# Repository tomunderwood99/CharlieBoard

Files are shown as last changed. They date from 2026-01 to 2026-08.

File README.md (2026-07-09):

# The CharlieBoard







An open-source LED display system for the MBTA that runs on Raspberry Pi Zero 2W with WS2812B LEDs. Features real-time transit data visualization, web control interface, and geographically accurate station mapping. PCBs for the Red, Orange, and Blue line are live! Green line in progress :)

CharlieBoard Display

## Quick Start

**Prerequisites:** 
- Raspberry Pi Zero 2W with Debian Trixie 64-bit Lite
- WS2812B LED strip or custom PCB
- WiFi (configured during pi setup)
- SSH enabled (RPI Connect recommended)
- [MBTA API key](https://api-v3.mbta.com/)

For hardware assembly instructions, see the [Hardware Assembly Guide](docs/hardware_assembly_guide.md).

Run the following commands to install and initialize the display.

```bash
sudo apt update && sudo apt install -y git python3-pip

cd ~
git clone --filter=blob:none --sparse https://github.com/tomunderwood99/CharlieBoard.git

cd CharlieBoard
git sparse-checkout set --no-cone '/*' '!hardware'

chmod +x deployment/quick_start/setup_mbta_controller.sh

# Optional: use flags to set custom recovery wifi settings:
# --with-wifi-helper
# --ap-ssid "CustomWifiName"
# --ap-password "YourStrongPassword"

sudo ./deployment/quick_start/setup_mbta_controller.sh
```

The setup script will prompt for your MBTA API key and various setting inputs. After completion, access the web interface at `http://your-hostname.local:8000` on your local network. Settings can be changed from the web interface or from the command line using the `charlieboard` command. See the [CLI reference](docs/cli.md) for details.

**Optional enhancement:** Set up a reverse proxy to access the web interface at `http://hostname.local` without the port number. See the [nginx reverse proxy setup guide](docs/nginx_reverse_proxy_setup.md).

**Note:** The sparse-checkout excludes the `hardware/` directory (PCB design files) to speed up cloning. This setting persists across future `git pull` operations. If you need the hardware files, run: `git sparse-checkout disable`

## Features

- **Real-time Transit Data**: Live vehicle positions, occupancy, and speed data
- **Geographically Accurate**: Stations are marked on a real map
- **Web Control Interface**: Remote control from any device on your network
- **Customizable Display**: Adjustable brightness, colors, and display hours
- **Reliable Operation**: Automatic recovery, health monitoring, and maintenance

## Hardware

| Component | Notes |
|---|---|
| Raspberry Pi Zero 2W | Main controller |
| WS2812B LEDs | Custom PCB (\~\$120 for 5) or LED strips (\~\$20) |
| 5V 4A Power Supply | Powers Pi and LEDs |
| MicroSD Card (16GB+) | For OS and software |
| Display Enclosure | Picture frame or custom case |

**Total Cost**: $50–180 depending on LED choice

Complete PCB design files (Gerber + KiCad) are available in `hardware/PCB Production/`. See the [Bill of Materials](docs/bill_of_materials.md) for detailed pricing and sourcing.

## Documentation

| Guide | Description |
|---|---|
| [Quick Start Guide](deployment/quick_start/QUICK_START_GUIDE.md) | Step-by-step setup walkthrough |
| [Terminal CLI](docs/cli.md) | Change settings from SSH without the web UI |
| [Complete Setup Guide](docs/complete_setup_guide.md) | Detailed manual configuration |
| [Bill of Materials](docs/bill_of_materials.md) | Hardware pricing and sourcing |
| [Hardware Assembly](docs/hardware_assembly_guide.md) | PCB assembly instructions |
| [Operations & Troubleshooting](docs/operations_and_troubleshooting.md) | Maintenance and problem solving |
| [Transit System Adaptation](docs/transit_system_adaptation_guide.md) | Adapt for other transit systems |
| [Map Making with QGIS](docs/map_making_with_qgis.md) | Create custom transit maps ([example project](https://drive.google.com/drive/folders/1vFNIh-ThJNZXUUT2JSJMrOyUVWq9bhA2?usp=drive_link)) |

## Contributing

Contributions are welcome! Please:

1. Fork the repository
2. Create a feature branch (`git checkout -b feature/amazing-feature`)
3. Test on Raspberry Pi Zero 2W hardware
4. Commit your changes (`git commit -m 'Add amazing feature'`)
5. Push and open a Pull Request

Follow existing code style, update documentation for new features, and add comments for complex logic. Contributions to **software** are under the MIT License; contributions to **`hardware/`** design files are under CERN-OHL-S, as described in [License](#license).

## License

This repository uses two licenses:

| Scope | License | Full text |
|---|---|---|
| **Software** (Python, scripts, configs, docs outside `hardware/`, and everything except the `hardware/` tree) | [MIT License](https://opensource.org/licenses/MIT) | [LICENSE](LICENSE) |
| **`hardware/`** (PCB designs, KiCad projects, Gerbers, and related production files in this directory) | [CERN Open Hardware Licence v2 — Strongly Reciprocal (CERN-OHL-S)](https://ohwr.org/project/cernohl/wikis/Documents/CERN-OHL-version-2) | [LICENSE-CERN-OHL-S](LICENSE-CERN-OHL-S) |

Third-party materials bundled under `hardware/` may carry their own licenses (see notices in those subfolders).

Copyright © 2025 Thomas Underwood

<details>
<summary>Disclaimers & Attributions</summary>

### AI Assistance
This project was developed with the assistance of AI coding tools. All code has been reviewed, tested, and validated on actual hardware.

### Data Sources
This project uses data from:
- **MBTA and MassDOT** – Transit data via [MBTA V3 API](https://api-v3.mbta.com/)
- **MassGIS** – Geographic and mapping data

All data is provided "as is" without warranties. This project is not affiliated with, endorsed by, or sponsored by MBTA, MassDOT, MassGIS, or the Commonwealth of Massachusetts.
</details>

## Support

- Check the [Operations and Troubleshooting Guide](docs/operations_and_troubleshooting.md)
- Review logs: `sudo journalctl -u mbta_display -n 100`
- Open an issue on GitHub with your Pi model, OS version, and error details
- [MBTA V3 API Documentation](https://api-v3.mbta.com/) · [Raspberry Pi GPIO Pinout](https://pinout.xyz/) · [Adafruit NeoPixel Guide](https://learn.adafruit.com/adafruit-neopixel-uberguide)

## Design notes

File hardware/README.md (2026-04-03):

# Hardware

Design files in this directory (KiCad projects, Gerbers, BOM-related assets, and other PCB production materials) are licensed under **CERN Open Hardware Licence Version 2 — Strongly Reciprocal (CERN-OHL-S)**.

The complete license text is in the repository root: [LICENSE-CERN-OHL-S](../LICENSE-CERN-OHL-S). The rest of the CharlieBoard repository (software, deployment scripts, and documentation outside `hardware/`) is under the MIT License: [LICENSE](../LICENSE).

Some subfolders include third-party symbols or footprints with their own license files—check those folders for additional terms.

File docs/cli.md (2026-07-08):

# CharlieBoard terminal CLI

Manage display settings from SSH or Raspberry Pi Connect without using the web UI on port 8000.

Install with the project (`pip install -e .`). The setup script puts `venv/bin` on your PATH in `/etc/profile.d/mbta_led_controller.sh`, so `charlieboard` works in new SSH or Pi Connect sessions. In the same terminal window where you just ran setup, use the full path once: `~/CharlieBoard/venv/bin/charlieboard show`.

## Commands

### Show settings

```bash
charlieboard show
```

Prints route, display mode, power, bedtimes, brightness, and colors.

### Set display mode

```bash
charlieboard set mode vehicles    # vehicles | occupancy | speed | rainbow
```

Picked up by the running display on the next MBTA stream event (usually within seconds).

### Set power

```bash
charlieboard set power on
charlieboard set power off
```

### Set brightness

```bash
charlieboard set brightness 0.5
charlieboard set brightness 1.0
```

Brightness is on a 0.0–1.0 scale (same as the web UI slider). Picked up by the running display on the next stream event.

### Set bedtimes

```bash
charlieboard set bedtime --start 22:00 --end 07:00
charlieboard set bedtime --start 23:30    # end unchanged
charlieboard set bedtime --end 06:00      # start unchanged
```

Times use 24-hour `HH:MM` format.

### Set colors (legend / color keys)

```bash
charlieboard set color stopped 255,0,0
charlieboard set color incoming #ff4b4b
charlieboard set color max_occupancy 255 128 0
```

**Color names**

| Mode | Names |
|---|---|
| vehicles | `stopped`, `incoming`, `transit` |
| speed | `min_speed`, `max_speed`, `null_speed` |
| occupancy | `min_occupancy`, `max_occupancy`, `null_occupancy` |

**Color formats:** `#RRGGBB`, `R,G,B`, or `R G B` (0–255 per channel).

### Set route

```bash
sudo charlieboard set route Green-B
```

Valid routes: `Red`, `Blue`, `Orange`, `Green-All`, `Green-B`, `Green-C`, `Green-D`, `Green-E`.

Route changes require restarting services (station maps and the MBTA stream filter are set at startup). The CLI restarts `mbta_display` and `mbta_monitor` automatically after saving. Use `sudo` if `systemctl restart` needs elevated permissions.

### Custom .env path

```bash
charlieboard --env /path/to/.env show
```

## Web UI sync

- Settings are stored in `.env`; the web UI reads the same file on page load (`GET /get_settings`).
- Reload the browser after CLI changes to refresh the form.
- The web UI does not display route (setup-only); saving from the web will not overwrite a CLI route change.

## Related commands

| Command | Purpose |
|---|---|
| `display_status` | System health and metrics |
| `display_reboot` | Restart display + monitor services |

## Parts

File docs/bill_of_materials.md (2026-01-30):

# Bill of Materials

Complete parts list for building The CharlieBoard.

## Cost Summary

| Category | Cost |
|---|---|
| Electronics | ~$165 |
| Hardware & Enclosure | ~$12 |
| **Total** | **~$177** |

*Most of the cost is the custom PCB (5-board minimum). Using LED strips instead brings total to ~$50.*

## Electronics

| Component | Qty | Price | Notes |
|---|-----|---|---|
| Raspberry Pi Zero 2W | 1 | $15 | Main controller |
| MicroSD Card (16GB+) | 1 | $8 | For OS and software |
| Custom PCB | 5 | $120 | With 47 WS2812B LEDs (assembled, min order 5) |
| 5V 4A USB-C Power Supply | 1 | $12 | Powers Pi and LEDs |
| USB-C to Wire Connector | 1 | $3 | Power connection |
| 1N5819 Schottky Diode | 1 | $0.25 | Protects GPIO pin |
| 3-pin JST Connectors | 2 | $1.50 | PCB power connection |
| Misc Wires | 1 set | $3 | Hookup wire |
| Heat Shrink Tubing | 1 set | $2 | Wire insulation |

## Hardware & Enclosure

| Component | Qty | Price | Notes |
|---|-----|---|---|
| 8"×10" Picture Frame | 1 | $10 | Display enclosure (remove glass) |
| 3D Printed Pi Case | 1 | $0.50 | ~15g PLA |
| M2.5×12mm Screws | 4 | $0.60 | Pi mounting |
| M2.5 Nuts | 4 | $0.40 | Pi mounting |

## Component Notes

### Raspberry Pi Zero 2W
Tested on Zero 2W, should work on Pi 3/4/5. Purchase from [Adafruit](https://www.adafruit.com/), [PiShop](https://www.pishop.us/), or [CanaKit](https://www.canakit.com/).

### Custom PCB
- Design files in `hardware/PCB Production/`
- Recommended: [JLCPCB](https://jlcpcb.com/) with assembly service
- WS2812B-2020 LEDs require baking before assembly—see [datasheet](https://www.mouser.com/pdfDocs/WS2812B-2020_V10_EN_181106150240761.pdf)

### 1N5819 Schottky Diode
Protects GPIO from backflow current. Critical for safe operation.

### Picture Frame
8"×10" works for Red Line PCB. Remove glass; modify back panel for JST connector clearance.

### 3D Printed Case
STL files in `hardware/RPI Case/`. Print at home or order from Craftcloud, Shapeways, etc.

## Budget Build (~$50)

Skip the custom PCB for a minimal working system:

| Component | Price |
|---|---|
| Raspberry Pi Zero 2W | $15 |
| MicroSD Card | $8 |
| WS2812B LED Strip | $12 |
| 5V Power Supply | $10 |
| Misc Electronics | $5 |

**Trade-off:** Not geographically accurate, requires custom mounting.

## Self-Assembly PCB Option

Order bare PCBs (~$2–5 each) and hand-solder components.
- **Savings:** ~$60–80 per board
- **Difficulty:** High—WS2812B-2020 LEDs are 2mm × 2mm, requires reflow oven

## Bulk Orders

Custom PCB cost drops significantly with quantity. At 5 boards, cost is ~$24/board, bringing total build cost to ~$80 if the boards are split between 5 people.

## Where to Buy

| Category | Suppliers |
|---|---|
| Electronics | Adafruit, DigiKey, Mouser, Amazon |
| PCB Manufacturing | JLCPCB (recommended), PCBWay, OSH Park |
| 3D Printing | Local maker spaces, Craftcloud, Shapeways |

## Not Included

- Soldering equipment (iron, solder, flux)
- Tools (wire strippers, screwdrivers, multimeter)
- Prices are estimates and vary by region/supplier

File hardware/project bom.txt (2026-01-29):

1x PCB or WS2812 string with appropriate leds (47 for Red Line)
1x Raspberry Pi Zero 2W
1x MicroSD Chip
1x 8"x10" Picture Frame
1x 3D printed RPI case
4x M2.5x12mm screws
4x M2.5 nuts 

1x 5v4A USBC Power Supply (can sub for other connection type)
1x 1N5819 Schottky Diode
1x USBC-to-wire connector
1x 3 pin JST female surface mount connector
1x 3 pin JST male wired connector
Misc wires
Soldering station
Heat shrink tubing

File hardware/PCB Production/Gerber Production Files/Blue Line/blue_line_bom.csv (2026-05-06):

Comment | Designator | Footprint | JLCPCB Part #_optional_
WS2812B-202 | D1,D2,D3,D4,D5,D6,D7,D8,D9,D10,D11,D12,D13,D14,D15,D16,D17,D18,D19,D20,D21,D22,D23,D24 | LED_WS2812B-2020 | C965555

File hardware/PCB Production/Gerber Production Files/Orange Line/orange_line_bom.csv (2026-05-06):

Comment | Designator | Footprint | JLCPCB Part #_optional_
WS2812B-202 | D1,D2,D3,D4,D5,D6,D7,D8,D9,D10,D11,D12,D13,D14,D15,D16,D17,D18,D19,D20,D21,D22,D23,D24,D25,D26,D27,D28,D29,D30,D31,D32,D33,D34,D35,D36,D37,D38,D39,D40 | LED_WS2812B-2020 | C965555

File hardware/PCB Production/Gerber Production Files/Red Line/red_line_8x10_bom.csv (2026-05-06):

Comment | Designator | Footprint | JLCPCB Part #_optional_
WS2812B-2020 | U2, U3, U4, U5, U6, U7, U8, U9, U10, U11, U12, U13, U14, U15, U16, U17, U18, U19, U20, U21, U22, U23, U24, U25, U26, U27, U28, U29, U30, U31, U32, U33, U34, U35, U36, U37, U38, U39, U40, U41, U42, U43, U44, U45, U46, U47, U48 | LED_WS2812B-2020 | C965555

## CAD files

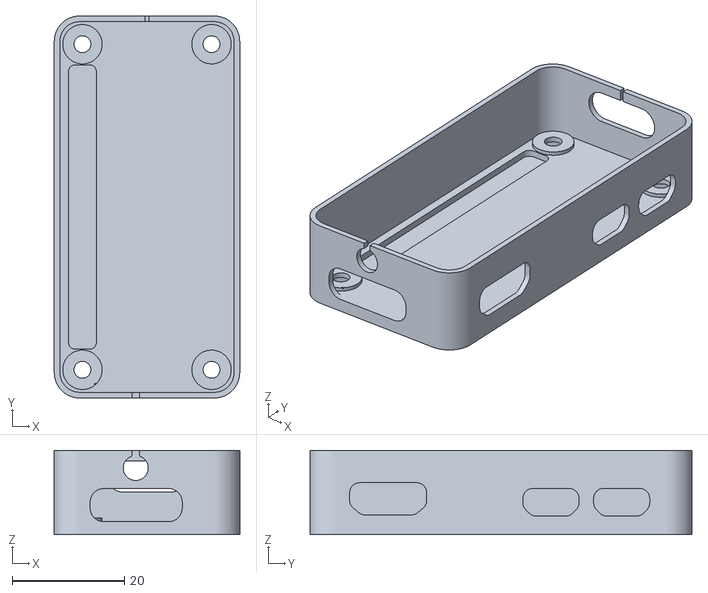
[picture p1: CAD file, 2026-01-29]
hardware/RPI Case/rpi_z2w_case_body.stl
33.0 x 68.0 x 15.0

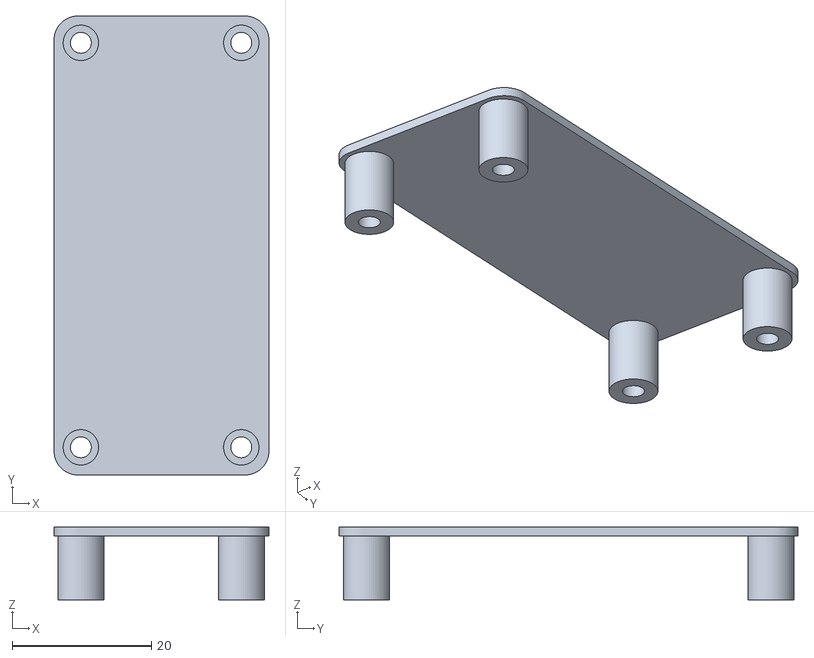
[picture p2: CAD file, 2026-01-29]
hardware/RPI Case/rpi_z2w_case_lid.stl
30.8 x 65.8 x 10.4

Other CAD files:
hardware/RPI Case/rpi_z2w_case.f3z

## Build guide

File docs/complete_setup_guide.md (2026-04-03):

# Complete Setup Guide

This guide walks through setting up **CharlieBoard** on a fresh Raspberry Pi Zero 2W manually. For most users, the [Quick Start Guide](../deployment/quick_start/QUICK_START_GUIDE.md) or the automated installer (below) is faster.

**Automated setup (recommended):** From the repository root on the Pi, run:

```bash
cd ~/CharlieBoard   # or your clone directory
chmod +x deployment/quick_start/setup_mbta_controller.sh
sudo ./deployment/quick_start/setup_mbta_controller.sh
```

That script performs the same stages as this document: system packages, timezone, virtualenv, `pip install -e .`, `.env` creation, systemd unit path patching, log directory, service install, optional LED test, and `display_status` / `display_reboot` aliases in `~/.bashrc`. Use this guide if you need to install or debug step by step.

**Note:** This covers software setup only. For hardware assembly, see the [Hardware Assembly Guide](hardware_assembly_guide.md) first.

## Table of Contents

1. [Prepare Your Raspberry Pi](#step-1-prepare-your-raspberry-pi)
2. [System Update and Core Tools](#step-2-system-update-and-core-tools)
3. [Clone the Repository](#step-3-clone-the-repository)
4. [Configure Timezone](#step-4-configure-timezone)
5. [Set Up Python Environment](#step-5-set-up-python-environment)
6. [Install Dependencies](#step-6-install-dependencies)
7. [Set Up Raspberry Pi Connect (Optional)](#step-7-set-up-raspberry-pi-connect-optional)
8. [Create Configuration File](#step-8-create-configuration-file)
9. [Configure LED Mappings (Optional)](#step-9-configure-led-mappings-optional)
10. [Test LED Hardware](#step-10-test-led-hardware)
11. [Test Full Application](#step-11-test-full-application)
12. [Patch Paths in Systemd Unit Files](#step-12-patch-paths-in-systemd-unit-files)
13. [Install and Enable Services](#step-13-install-and-enable-services)
14. [Verify Services](#step-14-verify-services)
15. [Set Up Convenience Aliases (Optional)](#step-15-set-up-convenience-aliases-optional)
16. [Access Web Interface](#step-16-access-web-interface)

## Step 1: Prepare Your Raspberry Pi

1. **Flash Raspberry Pi OS** using [Raspberry Pi Imager](https://www.raspberrypi.com/software/):
   - Choose **Raspberry Pi OS Lite (64-bit)**
   - Configure WiFi and SSH in imager settings
   - Set hostname (e.g., `mbta-display`)
   - Set username and password

2. **Connect via SSH:**
   ```bash
   ssh pi@mbta-display.local
   # or: ssh pi@192.168.1.xxx
   ```

## Step 2: System Update and Core Tools

The automated installer runs `apt-get update` and installs the packages below (it does not run a full `dist-upgrade`). Match that set for manual setup:

```bash
sudo apt update
sudo apt install -y python3 python3-pip python3-venv python3-dev git
# Optional but recommended for a new image:
# sudo apt upgrade -y
```

Verify:

```bash
git --version && python3 --version
```

Python 3.7+ is required (`timedatectl` and `systemctl` are expected on Raspberry Pi OS).

## Step 3: Clone the Repository

```bash
cd ~
git clone https://github.com/tomunderwood99/CharlieBoard.git
cd CharlieBoard

# Optional: Remove hardware folder to save space
rm -rf hardware/
echo "hardware/" >> .git/info/exclude
```

The installer expects to be run from the directory that contains `runtime/startup.py` and `setup.py` (repository root).

## Step 4: Configure Timezone

The setup script configures timezone **before** creating the virtualenv. Set yours explicitly:

```bash
sudo timedatectl set-timezone America/New_York
timedatectl
```

Other US examples: `America/Chicago`, `America/Denver`, `America/Los_Angeles`.

## Step 5: Set Up Python Environment

```bash
cd ~/CharlieBoard
python3 -m venv venv
source venv/bin/activate
pip install --upgrade pip

# Verify: should show .../CharlieBoard/venv/bin/python (path depends on user and clone location)
which python
```

The installer creates the venv as your normal user (`SUDO_USER`), not as root.

## Step 6: Install Dependencies

```bash
pip install -e .
```

Verify key packages:

```bash
pip list | grep -E "Flask|neopixel|rpi-ws281x"
```

If installation fails, the installer suggests:

```bash
sudo apt install -y build-essential python3-dev
# For some rpi_ws281x build issues:
sudo apt install -y scons swig
```

Then retry `pip install -e .` (or `pip install -e . -v` for verbose output).

## Step 7: Set Up Raspberry Pi Connect (Optional but Recommended)

[Raspberry Pi Connect](https://www.raspberrypi.com/documentation/services/connect.html) provides secure remote access via web browser—no port forwarding or VPN needed. Manage your display from anywhere.

```bash
sudo apt install rpi-connect
rpi-connect signin
```

Visit the displayed URL to complete sign-in with your [Raspberry Pi ID](https://id.raspberrypi.com). After setup, access your Pi at [connect.raspberrypi.com](https://connect.raspberrypi.com).

## Step 8: Create Configuration File

Create `.env` in the project root (`~/CharlieBoard/.env`). The installer writes this template (adjust values as needed):

```bash
nano .env
```

Contents (same fields as the setup script):

```bash
# CharlieBoard / MBTA configuration

MBTA_API_KEY=your_api_key_here

# Display settings
ROUTE=Red
BRIGHTNESS=0.5
POWER_SWITCH=on
BEDTIME_START=22:00
BEDTIME_END=06:00
DISPLAY_MODE=vehicles

# Color settings (RGB values)
STOPPED_COLOR=[255, 0, 0]
INCOMING_COLOR=[255, 75, 75]
TRANSIT_COLOR=[150, 150, 150]
MIN_SPEED_COLOR=[0, 255, 0]
MAX_SPEED_COLOR=[255, 0, 0]
NULL_SPEED_COLOR=[0, 0, 255]
MIN_OCCUPANCY_COLOR=[0, 255, 0]
MAX_OCCUPANCY_COLOR=[255, 0, 0]
NULL_OCCUPANCY_COLOR=[0, 0, 255]

# Debug settings
SHOW_DEBUGGER_OPTIONS=false
DEBUGGER=[]
```

Get a free API key at [api-v3.mbta.com](https://api-v3.mbta.com/). For `ROUTE`, the installer offers Red, Blue, Orange, Green-All, Green-B, Green-C, Green-D, and Green-E.

## Step 9: Configure LED Mappings (Optional)

If customizing LED positions:

```bash
nano config/station_led_maps.py
nano config/station_id_maps.py
```

## Step 10: Test LED Hardware

```bash
cd ~/CharlieBoard
source venv/bin/activate

# Edit LED_COUNT in test script if needed
nano tests/red_test.py

# Run test (requires sudo for GPIO)
sudo -E venv/bin/python tests/red_test.py
```

All LEDs should turn red. Press Ctrl+C to exit.

**If LEDs don't light up**, check:

- Data wire → GPIO 18 (physical pin 12)
- Ground shared between Pi and LED power supply
- LEDs have adequate 5V power

## Step 11: Test Full Application

```bash
cd ~/CharlieBoard
source venv/bin/activate
sudo venv/bin/python runtime/startup.py
```

This starts the web interface (port 8000) and LED controller. Verify at `http://mbta-display.local:8000` (or `/$(hostname).local:8000`).

Press Ctrl+C to stop.

## Step 12: Patch Paths in Systemd Unit Files

Checked-in unit files under `deployment/systemd/` use placeholder paths. The installer **`sed`-replaces** them so `WorkingDirectory`, `Environment=PROJECT_ROOT`, `Environment=VENV_PATH`, `ExecStart` (and the `daily_reboot` log line) point at your clone. From the repository root, run the same substitutions (adjust directory if your clone is not `~/CharlieBoard`):

```bash
cd ~/CharlieBoard
PROJECT_DIR="$(pwd)"
VENV_PATH="$PROJECT_DIR/venv"

sed -i "s|WorkingDirectory=.*|WorkingDirectory=$PROJECT_DIR|g" deployment/systemd/mbta_display.service
sed -i "s|Environment=PROJECT_ROOT=.*|Environment=PROJECT_ROOT=$PROJECT_DIR|g" deployment/systemd/mbta_display.service
sed -i "s|Environment=VENV_PATH=.*|Environment=VENV_PATH=$VENV_PATH|g" deployment/systemd/mbta_display.service
sed -i "s|ExecStart=.*|ExecStart=$VENV_PATH/bin/python $PROJECT_DIR/runtime/startup.py|g" deployment/systemd/mbta_display.service

sed -i "s|WorkingDirectory=.*|WorkingDirectory=$PROJECT_DIR|g" deployment/systemd/mbta_monitor.service
sed -i "s|Environment=PROJECT_ROOT=.*|Environment=PROJECT_ROOT=$PROJECT_DIR|g" deployment/systemd/mbta_monitor.service
sed -i "s|Environment=VENV_PATH=.*|Environment=VENV_PATH=$VENV_PATH|g" deployment/systemd/mbta_monitor.service
sed -i "s|ExecStart=.*|ExecStart=$VENV_PATH/bin/python -u $PROJECT_DIR/monitoring/health_monitor.py|g" deployment/systemd/mbta_monitor.service

sed -i "s|WorkingDirectory=.*|WorkingDirectory=$PROJECT_DIR|g" deployment/systemd/daily_reboot.service
sed -i "s|ExecStartPre=.*|ExecStartPre=/bin/sh -c 'echo \"\$(date): Initiating scheduled daily reboot\" >> $PROJECT_DIR/logs/daily_reboot.log'|g" deployment/systemd/daily_reboot.service
```

If you prefer editing by hand, ensure those fields match your `PROJECT_DIR` and `VENV_PATH`. The monitor unit keeps `ExecStartPre=/bin/sleep 15` as in the template.

## Step 13: Install and Enable Services

```bash
cd ~/CharlieBoard
mkdir -p logs

sudo cp deployment/systemd/mbta_display.service /etc/systemd/system/
sudo cp deployment/systemd/mbta_monitor.service /etc/systemd/system/
sudo cp deployment/systemd/daily_reboot.service /etc/systemd/system/
sudo cp deployment/systemd/daily_reboot.timer /etc/systemd/system/

sudo systemctl daemon-reload
```

Enable **the timer** for scheduled reboots (do not enable `daily_reboot.service` directly—it is triggered by the timer), matching the installer:

```bash
sudo systemctl enable mbta_display.service mbta_monitor.service daily_reboot.timer
sudo systemctl start mbta_display.service mbta_monitor.service
```

Daily reboot is scheduled by `daily_reboot.timer` (installer messaging refers to a 3 AM reboot). Inspect with:

```bash
sudo systemctl list-timers daily_reboot.timer
```

## Step 14: Verify Services

```bash
sudo systemctl status mbta_display.service
sudo systemctl status mbta_monitor.service

# View live logs
sudo journalctl -u mbta_display -f
```

All services should show "active (running)".

## Step 15: Set Up Convenience Aliases (Optional)

The installer appends these to `~/.bashrc` using the **venv’s** `python3` and absolute project paths (same effect as below):

```bash
echo '' >> ~/.bashrc
echo '# CharlieBoard quick status command' >> ~/.bashrc
echo "alias display_status='$HOME/CharlieBoard/venv/bin/python3 $HOME/CharlieBoard/runtime/status_check.py'" >> ~/.bashrc
echo '# CharlieBoard quick reboot command' >> ~/.bashrc
echo "alias display_reboot='sudo systemctl restart mbta_display.service && sudo systemctl restart mbta_monitor.service && echo \"Services restarted successfully\"'" >> ~/.bashrc
source ~/.bashrc
```

If your clone directory is not `~/CharlieBoard`, replace both path fragments in the `display_status` line (the installer uses the actual `PROJECT_DIR` from when you ran it).

Test the status script without the alias:

```bash
"$HOME/CharlieBoard/venv/bin/python3" "$HOME/CharlieBoard/runtime/status_check.py"
```

## Step 16: Access Web Interface

Open in your browser:

```
http://mbta-display.local:8000
```

Or use your Pi’s IP: `http://192.168.1.xxx:8000`

**Features:**

- Switch display modes (vehicles, occupancy, speed, rainbow)
- Adjust brightness
- Change routes
- Configure bedtime hours
- Monitor system health

**Optional:** Set up [nginx reverse proxy](nginx_reverse_proxy_setup.md) to access at `http://mbta-display.local` without the port number.

## Troubleshooting

See [Operations & Troubleshooting](operations_and_troubleshooting.md) for common issues and solutions.

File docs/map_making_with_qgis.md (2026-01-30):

# Map Making with QGIS

Create custom transit maps using QGIS and MassGIS data for PCB design or display visualizations. 

I am by no means a QGIS expert, and this guide is a work in progress. I taught myself QGIS through trial and error, YouTube, and asking questions to LLMs. If you have any suggestions for improvements or need help, please feel free to reach out.

> **System Requirements:** QGIS is computationally intensive. Recommended: 16GB+ RAM, dedicated GPU, SSD. Minimum: 8GB RAM, modern multi-core processor.

## Example Project

A ready-to-use QGIS example is available on Google Drive: **[QGIS Example](https://drive.google.com/drive/folders/1vFNIh-ThJNZXUUT2JSJMrOyUVWq9bhA2?usp=drive_link)**. It includes:

- Pre-processed layers (MassDOT Roads, Hydrography 25k, MBTA rapid transit lines, open space)
- A saved project file (`qgis_example_map.qgz`) you can open in QGIS
- A 4×4 example PDF for reference

Download the folder contents and open the `.qgz` file in QGIS to explore the layer setup and styling used for CharlieBoard-style maps.

## Overview

1. [Install QGIS](#install-qgis)
2. [Download Data](#download-data)
3. [Set Up Project](#set-up-project)
4. [Add & Style Layers](#add--style-layers)
5. [Create Print Layout](#create-print-layout)
6. [Export](#export)

## Install QGIS

Download the **Long Term Release (LTR)** from [qgis.org/download](https://qgis.org/download/).

## Download Data

MassGIS provides free geographic data: [mass.gov/info-details/massgis-data-layers](https://www.mass.gov/info-details/massgis-data-layers)

**Recommended layers:**
- [MassDOT Roads](https://www.mass.gov/info-details/massgis-data-massgis-massdot-roads)
- [Hydrography 25k](https://www.mass.gov/info-details/massgis-data-massdep-hydrography-125000)
- [MBTA Rapid Transit](https://www.mass.gov/info-details/massgis-data-mbta-rapid-transit)
- [Open Space](https://www.mass.gov/info-details/massgis-data-protected-and-recreational-openspace)

## Set Up Project

1. `Project > New`, then `Project > Save As` (e.g., "MBTA_RedLine_Map.qgz")
2. Set CRS: `Project > Properties > CRS` → **EPSG:26986** (Massachusetts State Plane NAD83)

**Tip:** Keep downloaded data in the same folder as your project file.

## Add & Style Layers

### Adding Layers

In the Browser panel, navigate to your data folder and double-click layers to add:
- Use POLY.shp files for filled areas (parks, water)
- For MBTA: import both ARC (tracks) and NODES (stations)
- For roads: EOTMAJROADS_ARC and EOTMINROADS_ARC

### Layer Order (top to bottom)

1. MBTA Nodes
2. MBTA Arc
3. Roads (Major)
4. Roads (Minor)
5. Water Bodies
6. Parks/Open Space

### Fix Water Layer Boundaries

Remove internal boundary lines in water layer:
1. `Processing > Toolbox` → "Fix Geometry" → Run on water layer
2. `Processing > Toolbox` → "Dissolve" → Run on fixed layer (leave dissolve fields empty)
3. Delete old water layers

### Styling Examples

**Water (Blue):** Right-click → Properties > Symbology → Simple fill
- Fill: #A5BFDD, Stroke: #000000 (0.2mm)

**Parks (Green):** Simple fill
- Fill: #C7E9C0, Stroke: #31A354 (0.1mm)

**Roads:** Categorized by "CLASS" field
- Class 1: 1.0mm, Class 2: 0.5mm, Class 3: 0.3mm, Color: #000000

**MBTA Lines:** Categorized by "LINE" field
- Red: #DA291C, Orange: #ED8B00, Blue: #003DA5, Green: #00843D
- Width: 1–3mm

**Station Labels:** Properties > Labels > Single Labels
- Select station name field, 8–10pt font, white buffer (1mm)

## Create Print Layout

1. `Project > New Print Layout` → Name it
2. Set page size in Item Properties
3. `Add Item > Add Map` → Draw rectangle
4. Configure in Item Properties:
   - Set scale (1:100k works for Red Line on 8"×10")
   - Use "Move Item Content" to position
   - Add 0.25–0.5" margins
   - Lock map when done
5. Add: Scale bar, North arrow, Title (`Add Item` menu)

## Export

### For PCB Design (SVG)

1. `Layout > Export as SVG`
2. Open in Illustrator/Inkscape
3. Simplify paths, adjust positions
4. Convert to black/white (KiCad sees only filled/not-filled)
5. Use Minus Front/Cropping for proper rendering
6. Save as plain SVG
7. Import to KiCad, place LEDs, connect, manufacture

**Tip:** For PCB design help, use online tutorials and LLMs. I was entirely self-taught this way!

### For General Display

Export as PNG or PDF at 300 DPI. PDFs maintain vector quality.

## Tips

### Performance
- Simplify geometries: `Vector > Geometry Tools > Simplify` (10–50m tolerance)
- Create spatial indexes: Layer Properties > Source
- Use scale-dependent rendering
- Clip data to your area of interest

### PCB Considerations
- Exact geographic accuracy isn't always practical - when working with extremely dense transit areas, even tiny WS2812B-2020 LEDs would overlap. With this in mind, you may have to scale up your display significantly, reduce the number of LEDs (less lines, or 1/line), or use a diagram instead of a map.
- Print at 100% scale on paper to verify LED placement

### Attribution

Include in documentation:
```
Map data provided by MassGIS. Data is provided "as is" and may not be accurate or current.
```

## Troubleshooting

| Issue | Solution |
|---|---|
| Layer won't load | Ensure all shapefile components (.shp, .shx, .dbf, .prj) are together |
| Map distorted | Verify all layers use EPSG:26986 |
| QGIS slow/crashes | Close unnecessary layers, filter features, restart periodically |
| Roads too cluttered | Filter to Class 1 only, use scale-dependent rendering |

## Resources

- [QGIS Example (Google Drive)](https://drive.google.com/drive/folders/1vFNIh-ThJNZXUUT2JSJMrOyUVWq9bhA2?usp=drive_link) – Layers + project file + example PDF
- [QGIS Documentation](https://docs.qgis.org/)
- [QGIS Tutorials](https://www.qgistutorials.com/)
- MassGIS Contact: massgismail@mass.gov

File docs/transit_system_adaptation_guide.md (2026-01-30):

# Transit System Adaptation Guide

How to adapt The CharlieBoard for transit systems other than the MBTA.

**Disclaimer:** This guide was written with AI assistance and hasn't been fully tested. If you complete an adaptation, please share your experience!

## Overview

### What's MBTA-Specific

| Component | File | Change Required |
|---|---|---|
| API Integration | `main/mbta_stream.py` | Yes |
| Station ID Maps | `config/station_id_maps.py` | Yes |
| Station LED Maps | `config/station_led_maps.py` | Yes |
| PCB/Map Design | `hardware/` | Yes |

### What's Reusable As-Is

- LED Controller (`display/controller/`)
- Display Modes (`display/modes/`)
- Web Interface (`web_interface/`)
- Monitoring (`monitoring/`)
- System Services (`deployment/systemd/`)

## Prerequisites

- Python proficiency
- Understanding of REST APIs
- Your transit system's API documentation and credentials
- Geographic data for your transit system (OpenStreetMap, local GIS)
- QGIS or similar for map creation

## Step 1: Research Your Transit API

### Common API Standards
- **GTFS Realtime** - North American and European systems
- **SIRI** - Common in Europe
- **Custom REST** - TfL, NYC MTA, etc.

### Required Data
   - ✅ Real-time vehicle positions
   - ✅ Vehicle direction/destination
   - ✅ Station/stop associations
- ⚠️ Occupancy (optional)
- ⚠️ Speed (optional)

### API Resources by Region

| Region | Resources |
|---|---|
| **US** | [NYC OpenData](https://opendata.cityofnewyork.us/), [Chicago Data Portal](https://data.cityofchicago.org/) |
| **UK** | [TfL Open Data](https://tfl.gov.uk/info-for/open-data-users/) |
| **Europe** | [Île-de-France Mobilités](https://data.iledefrance-mobilites.fr/), [Berlin Open Data](https://daten.berlin.de/) |
| **General** | [OpenStreetMap](https://www.openstreetmap.org/) |

## Step 2: Create Station ID Maps

Maps API station identifiers to human-readable names.

```python
# config/station_id_maps.py

def your_line_map():
    return {
        'API_STATION_ID_1': 'Station Name',
        'API_STATION_ID_2': 'Station Name',
        # Multiple IDs can map to same station (platforms, directions)
        'station_platform_1': 'Central Station',
        'station_platform_2': 'Central Station',
    }

station_id_maps = {
    "YourLine": your_line_map,
}
```

**Tip:** Create a discovery script to find all station IDs from your API:
```python
import requests
response = requests.get("https://api.yourtransit.com/vehicles")
station_ids = set(v['stop_id'] for v in response.json()['vehicles'])
for sid in sorted(station_ids):
    print(f"'{sid}': 'STATION_NAME',")
```

## Step 3: Create Station LED Maps

Maps station names to physical LED positions.

```python
# config/station_led_maps.py

def your_line_led_map():
    return (
        # Direction 1 (e.g., outbound)
        {
            "Start Station": 0,
            "Station 2": 1,
            "Station 3": 2,
            "End Station": 3,
        },
        # Direction 2 (e.g., inbound) - typically reverse order
        {
            "End Station": 7,
            "Station 3": 6,
            "Station 2": 5,
            "Start Station": 4,
        }
    )

station_led_maps = {
    "YourLine": your_line_led_map,
}
```

**LED Count:** `(stations × 2) + branches`

## Step 4: Modify API Integration

Modify `main/mbta_stream.py` for your API:

### Key Changes Needed

1. **API endpoint and authentication**
2. **Field name mapping** (your API → internal format)
3. **Streaming method** (SSE, WebSocket, or polling)

### Data Format Mapping

| Internal Field | Common API Variants |
|---|---|
| `id` | `vehicle_id`, `trip_id`, `label` |
| `current_status` | `status`, `state`, `position_status` |
| `direction_id` | `direction`, `route_direction_name` |
| `stop_id` | `station_id`, `current_stop` |

### Example: Polling-Based API

```python
class YourTransitStream:
    def poll_vehicles(self):
        response = requests.get(
            f"{self.api_base}/vehicles",
            headers={"Authorization": f"Bearer {self.api_key}"}
        )
        for vehicle in response.json()['data']:
            self.mode_manager.process_vehicle({
                'id': vehicle['vehicleId'],
                'stop_id': vehicle['currentStop']['id'],
                'current_status': self.map_status(vehicle['status']),
                'direction_id': 0 if vehicle['direction'] == 'outbound' else 1,
            })
        time.sleep(5)  # Poll interval
```

### Status Mapping

```python
def map_status(self, api_status):
    return {
        'APPROACHING': 'INCOMING_AT',
        'AT_STOP': 'STOPPED_AT',
        'DEPARTED': 'IN_TRANSIT_TO',
        'EN_ROUTE': 'IN_TRANSIT_TO',
    }.get(api_status, 'IN_TRANSIT_TO')
```

## Step 5: Create Your Map

Follow [Map Making with QGIS](map_making_with_qgis.md), substituting your region’s data and CRS. An example project (layers, QGIS project file, and PDF) is available in the [QGIS Example Google Drive folder](https://drive.google.com/drive/folders/1vFNIh-ThJNZXUUT2JSJMrOyUVWq9bhA2?usp=drive_link).

### Coordinate Reference System (CRS)

| City | CRS |
|---|-----|
| London | EPSG:27700 |
| NYC | EPSG:2263 |
| Paris | EPSG:27572 |
| Berlin | EPSG:25833 |
| Tokyo | EPSG:6677 |
| Sydney | EPSG:7856 |

### Official Line Colors

| System | Line | Hex |
|---|---|-----|
| London Underground | Central | `#DC241F` |
| NYC Subway | 1/2/3 | `#EE352E` |
| Paris Métro | M1 | `#FFCD00` |
| Berlin U-Bahn | U1 | `#55A030` |

## Step 6: Testing

### Validate Station Mappings

```python
from config.station_id_maps import station_id_maps
from config.station_led_maps import station_led_maps

def validate(line):
    id_map = station_id_maps[line]()
    outbound, inbound = station_led_maps[line]()
    
    id_stations = set(id_map.values())
    led_stations = set(outbound.keys())
    
    missing = id_stations - led_stations
    extra = led_stations - id_stations
    
    if missing: print(f"Missing in LED map: {missing}")
    if extra: print(f"Extra in LED map: {extra}")
    if not missing and not extra: print("✓ All stations mapped")

validate("YourLine")
```

### Test API Connection

```bash
curl -H "Authorization: Bearer YOUR_KEY" https://api.yourtransit.com/vehicles
```

### Test LEDs

   ```bash
sudo -E venv/bin/python tests/red_test.py
```

## Troubleshooting

| Issue | Cause | Solution |
|---|---|---|
| "Station not found" | Unknown ID from API | Add ID to station_id_maps.py |
| Wrong station lights up | Name mismatch | Check spelling/capitalization in both maps |
| No vehicles appear | API issue or wrong line name | Check API response, verify line identifier |
| Wrong direction | Direction mapping inverted | Swap outbound/inbound maps |
| Rate limiting | Polling too fast | Increase poll interval |

## Time Estimate

| Task | Hours |
|---|---|
| API research | 2–4 |
| Station ID mapping | 1–2 |
| LED position mapping | 2–3 |
| API integration code | 4–8 |
| Map creation (QGIS) | 3–6 |
| PCB design | 8–16 |
| Testing | 4–8 |
| **Total** | **24–47** |

## Contributing

If you adapt this for another transit system, consider contributing:
- Station maps (config files)
- API integration code
- PCB design files
- Documentation of challenges faced

**Good luck!** If you build displays for other systems, please share with the community.

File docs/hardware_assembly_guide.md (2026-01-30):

# Hardware Assembly Guide

Assembly instructions for your MBTA LED display. 

These instructions could be improved significantly through the addition of visuals or a video tutorial. I will work on this in the future, but in the meantime, please feel free to reach out with any questions or suggestions.

## Safety

- Work in ventilated area when soldering
- Disconnect power before making connections
- Double-check polarity (+5V and Ground) before powering on

## Tools Required

**Essential:**
- Soldering iron (300–350°C)
- Solder (60/40 or 63/37 rosin core)
- Wire strippers (22–24 AWG)
- Wire cutters
- Screwdriver

**Recommended:**
- Helping hands/third hand
- Multimeter

## Components

See [Bill of Materials](bill_of_materials.md) for complete list.

**Core:**
- Raspberry Pi Zero 2W
- MicroSD card (16GB+)
- WS2812B LED strip OR custom PCB
- 5V 4A USB-C power supply
- USB-C to wire connector
- 1N5819 Schottky diode
- Female Dupont connectors
- Heat shrink tubing
- Wires (22–24 AWG for data, 18–20 AWG for power)

**Optional:**
- Picture frame or enclosure
- JST connectors
- 3D printed Pi case

## Assembly Options

### Option 1: LED Strip (Cheapest)
- **Pros:** Quick, cheap, beginner-friendly
- **Cons:** Less professional appearance
- **Best for:** First builds, prototyping, tight budgets

### Option 2: Custom PCB (Best looking)
- **Pros:** Clean look, exact LED placement
- **Cons:** Higher cost, requires PCB fabrication
- **Best for:** Permanent installations

## Option 1: LED Strip Assembly

### Step 1: Prepare LED Strip

**LED counts per line (includes 3 LEDs for map legend):**
| Line | LEDs Needed |
|---|---|
| Red | 47 |
| Blue | 27 |
| Orange | 43 |
| Green (combined) | 131 |

Cut strip at marked cut points. Note data flow direction (arrows on strip).

### Step 2: Wire Connections

See [wiring diagram](../hardware/rpi_zero2w_ws2812b2020_wiring.pdf) or the image below for a basic wiring diagram. 

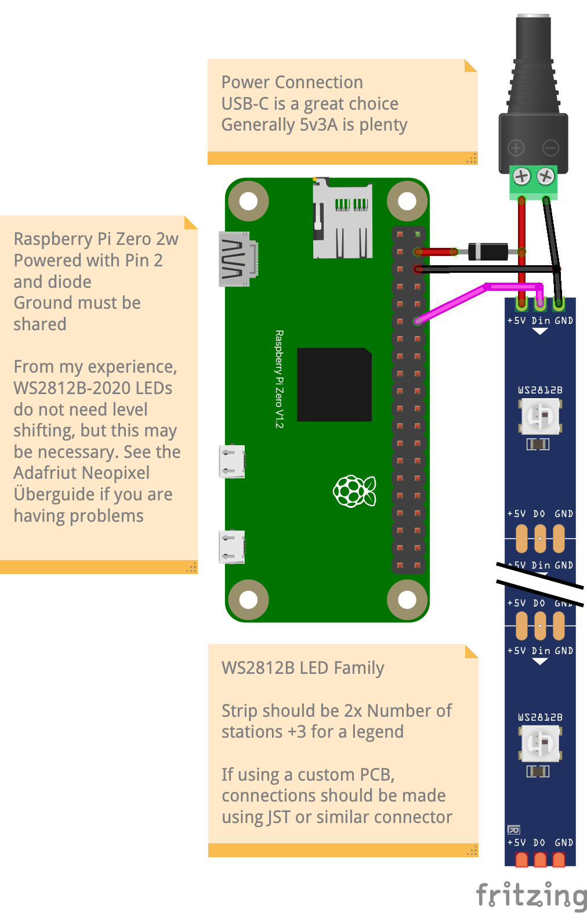
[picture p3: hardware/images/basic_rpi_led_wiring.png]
Basic Pi and LED wiring


1. **Data:** GPIO 18 (pin 12) → LED strip DIN
2. **Ground:** Pi ground → LED strip ground AND power supply ground (**all grounds must be common**)
3. **Power:** Pi pin 2 or 4 (flow into pi through 1N5819 Schottky diode) → LED strip 5V and power supply connector. 

These connections can be made using direct soldering, or a combination of connectors and wires. I recommend making a wire harness with the JST 3 pin cable, power supply connection, and Dupont connectors (see Option 2 Step 3 for more details).

**All solder joints should covered with heat shrink tubing**

### Step 3: Mount & Test

Mount LEDs to your display (poster, frame, etc.), then test with software.

## Option 2: Custom PCB Assembly

### Step 1: Order PCB

**Manufacturing files** in `hardware/PCB Production/`:
- `gerber_files.zip` - PCB fabrication
- `bom.csv` - Bill of materials
- `pos.csv` - Pick-and-place

**Recommended:** [JLCPCB](https://jlcpcb.com/) with assembly service (WS2812B-2020 LEDs are 2mm × 2mm).

**Specs:** 2-layer, 1.6mm thickness, 1oz copper, ENIG or HASL finish.

### Step 2: Inspect PCB

Check for:
- Cold solder joints
- Solder bridges
- Correct LED orientation

### Step 3: Connect to Pi

On the PCB, solder a JST 3 pin connector to the back of the board, noting the orientation of the pins. This will determine which wires in the JST 3 pin cable are connected to which pins on the PCB.

Create a cable with:
- JST 3 pin cable
- Power supply connection (USB-C to 2 wire connector)
- Dupont connectors (Pi GPIO side)
- Schottky diode (1N5819) on 5V line to protect Pi

**Connections:**
- Data → GPIO 18 (pin 12). Solder a modified female Dupont connector to the data wire in the JST 3 pin cable.
- Ground → Any ground pin on the Pi. Solder a modified female Dupont connector to the ground wire in the JST 3 pin cable and the ground wire in the power supply connection.
- 5V → Pin 2 or 4 (through diode). Solder a modified female Dupont connector to the 5V wire in the JST 3 pin cable and the 5V wire in the power supply connection.

**The Ground and 5V connection require three-way splicing! Take care that these are sturdy connections! Additionally, make sure to heat shrink the connections to protect them from short circuits.**

### Step 4: Final Assembly

1. Remove front glass from picture frame
2. Mount PCB with push tabs, screws, or adhesive
3. Connect the JST 3 pin cable to the PCB
4. Connect the Dupont connectors to the Pi GPIO pins for data, ground, and 5V
5. Position Pi accessibly but hidden
6. Connect the power supply to the cable (powering both the Pi and the LEDs)

## Testing

```bash
cd ~/mbta_led_controller
source venv/bin/activate
sudo -E venv/bin/python tests/red_test.py
```

All LEDs should turn red. Press Ctrl+C to exit.

## Common Mistakes

| Mistake | Result | Fix |
|---|---|-----|
| No common ground | LEDs don't work | Connect Pi ground to LED power supply ground |
| Schottky diode backwards | Pi does not boot | Check polarity of diode |
| Wrong LED direction | LEDs don't light | Check arrows on strip, data flows one direction |
| Insufficient power | Flickering | Use adequate supply (5V 3A+ for ~50 LEDs) |
| Powering LEDs from Pi | Dim/no light | Use separate 5V supply for LEDs |
| Wrong GPIO pin | No data | Use GPIO 18 (PWM-capable) |

## Next Steps

If software not installed, see [Quick Start Guide](../deployment/quick_start/QUICK_START_GUIDE.md).

For troubleshooting, see [Operations & Troubleshooting](operations_and_troubleshooting.md).

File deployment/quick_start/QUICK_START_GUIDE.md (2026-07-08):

# Quick Start Guide

Get your MBTA LED display running in under 10 minutes with the automated setup script.

## Prerequisites

1. Raspberry Pi with Raspberry Pi OS installed and booted
2. WiFi/network configured
3. SSH access to your Pi
4. Hardware connected (WS2812B LEDs, 5V power supply, common ground)

---

## Installation

### Step 1: Clone Repository

```bash
sudo apt update && sudo apt install -y git python3-pip
cd ~
git clone https://github.com/tomunderwood99/CharlieBoard.git
cd mbta_led_controller

# Optional: Remove hardware folder to save space
rm -rf hardware/
echo "hardware/" >> .git/info/exclude
```

### Step 2: Run Setup Script

```bash
chmod +x deployment/quick_start/setup_mbta_controller.sh
sudo ./deployment/quick_start/setup_mbta_controller.sh
```

### Step 3: Answer Prompts

| Prompt | Required | Default | Notes |
|---|---|---|---|
| Install WiFi Helper | No | No | Captive-portal WiFi setup on first boot ([details](#headless-wifi-setup-optional)) |
| MBTA API Key | Yes\* | — | Free at [api-v3.mbta.com](https://api-v3.mbta.com/) |
| Line | No | Red | Red, Blue, Orange, or Green |
| Timezone | No | Eastern | Select from menu |
| Bedtime Start/End | No | 22:00/06:00 | Auto-off hours |
| Brightness | No | 0.5 | 0.0–1.0 |
| LED Test | No | Yes | Tests hardware |
| Start Services | No | Yes | Start immediately |

\* The MBTA API key prompt becomes optional when the WiFi helper is installed — you can leave it blank and enter the key through the captive portal on first connection.

### Step 4: Done!

Access web interface at `http://your-hostname.local:8000`

### Optional Enhancements

**Raspberry Pi Connect** – Secure remote access from anywhere via web browser:
```bash
sudo apt install rpi-connect
rpi-connect signin
```
Then access your Pi at [connect.raspberrypi.com](https://connect.raspberrypi.com). See [official docs](https://www.raspberrypi.com/documentation/services/connect.html).

**nginx Reverse Proxy** – Access at `http://hostname.local` without the port number. See [nginx setup guide](../../docs/nginx_reverse_proxy_setup.md).

---

## Headless WiFi setup (optional)

Designed for boards that move between locations. The setup script can install [`tomunderwood99/headless_wifi_helper`](https://github.com/tomunderwood99/headless_wifi_helper) alongside CharlieBoard so the Pi can reconfigure WiFi (and the MBTA API key) from a phone — no re-flashing or wired connection required.

> **Requires Raspberry Pi OS Trixie.** The helper hard-depends on NetworkManager as the network backend (the default on Trixie). Older Bookworm/Bullseye images using `dhcpcd` + `wpa_supplicant` are *not* supported, and the helper's installer will fail. Once installed, CharlieBoard's runtime WiFi recovery (`monitoring/network_monitor.py`) and reboot-loop recovery (`monitoring/health_monitor.py`) also assume NetworkManager. Pass `--no-wifi-helper` to skip if you're not on Trixie.

### How it works

At boot, the helper's `wifi_configurator.service` runs **before** `network-online.target` — and CharlieBoard's services run **after** it — so the MBTA display always waits for WiFi to be ready.

```
Boot
 └─ NetworkManager.service
     └─ wifi_configurator.service           ← waits up to ~30s for wlan0
         ├─ wlan0 associated → exit 0
         └─ no association  → AP at 192.168.4.1, blocks until user reboots
     └─ network-online.target
         ├─ mbta_display.service
         └─ mbta_monitor.service
```

When the AP is up, connect to it from a phone (most devices auto-launch the captive portal; otherwise open `http://192.168.4.1`), pick a network, enter credentials, optionally paste an MBTA API key, hit **Save Credentials**, then **Reboot Now**. The helper writes the API key into CharlieBoard's `.env` as `MBTA_API_KEY=…` before the reboot.

### Enabling it

The setup script asks interactively (default **No** — just press Enter to skip). To skip the prompt entirely in either direction:

```bash
sudo ./deployment/quick_start/setup_mbta_controller.sh --with-wifi-helper
sudo ./deployment/quick_start/setup_mbta_controller.sh --no-wifi-helper
```

Additional flags forwarded to the helper's own `setup.sh`:

| Flag | Default | Purpose |
|---|---|---|
| `--wifi-helper-dir <path>` | `/home/<user>/headless_wifi_helper` | Where to clone the helper repo. |
| `--ap-ssid <ssid>` | `PiWifiSetup` | Captive-portal AP SSID. |
| `--ap-password <pw>` | autogenerated 16-char random | AP password (12+ chars required by the helper's policy). |

When `--with-wifi-helper` is selected, the MBTA API key prompt becomes optional — leave it blank during setup and enter it through the captive portal on first connection.

### Runtime behavior

If WiFi is lost while CharlieBoard is running, `monitoring/network_monitor.py` first tries to bounce `wlan0` in-process via `nmcli device disconnect/connect` (or `ip link` on non-NetworkManager systems). If that fails, `monitoring/health_monitor.py` will eventually reboot the Pi (the same path it already uses for unhealthy systems), and on the next boot the helper detects the missing WiFi and brings up the captive portal automatically.

The health monitor additionally guards against an "associated-but-blackholed" reboot loop: if `wlan0` is associated to a known SSID but no public Internet probe is reachable (bad upstream link, captive portal we can't authenticate against, ISP outage on that SSID), the monitor deletes the active NM connection just before rebooting. On the next boot the helper sees no STA association and opens the captive portal at `http://192.168.4.1` so you can pick a different network — instead of the Pi silently re-associating to the same dead SSID and rebooting again. The probe deliberately avoids the MBTA API, so an MBTA-side outage will *not* cause us to wipe your WiFi config. This safety net only activates when `wifi_configurator.service` is installed; without the helper, the connection profile is preserved across reboots.

### Diagnostics

```bash
systemctl status wifi_configurator.service
sudo journalctl -u wifi_configurator.service -f
```

See the helper's [README](https://github.com/tomunderwood99/headless_wifi_helper/blob/main/README.md) for additional helper configuration (regulatory domain, hand-edited unit overrides, etc.).

---

## What the Script Does

1. Updates system and installs packages
2. Creates Python virtual environment
3. Installs dependencies
4. Creates `.env` configuration
5. Configures and installs systemd services
6. Sets up convenience commands (`charlieboard` on PATH, `display_status`, `display_reboot`)
7. Optionally installs the headless WiFi helper (`wifi_configurator.service`)
8. Optionally tests LED hardware

---

## After Setup

### Quick Commands

```bash
charlieboard show       # On PATH after login (setup adds /etc/profile.d/mbta_led_controller.sh)
display_status          # Alias in ~/.bashrc — new SSH session, or: source ~/.bashrc
display_reboot          # Restart services
```

### Terminal settings (no web UI)

Useful over SSH or Raspberry Pi Connect when port 8000 is unreachable:

```bash
charlieboard show
charlieboard set power on
charlieboard set mode occupancy
charlieboard set bedtime --start 23:00 --end 06:30
charlieboard set color max_occupancy 255,128,0
sudo charlieboard set route Orange    # restarts display services
```

See [CLI reference](../../docs/cli.md) for color names and details.

### Service Management

```bash
sudo systemctl status mbta_display.service
sudo systemctl restart mbta_display.service
sudo journalctl -u mbta_display -f    # Live logs
```

### Change Configuration

Use the web interface (easiest), `charlieboard set ...`, or edit directly:
```bash
charlieboard show
nano ~/mbta_led_controller/.env
sudo systemctl restart mbta_display.service
```

---

## Troubleshooting

For detailed troubleshooting, see [Operations & Troubleshooting](../../docs/operations_and_troubleshooting.md).

### Quick Checks

| Issue | Command |
|---|---|
| LED test | `sudo -E venv/bin/python tests/red_test.py` |
| Service status | `sudo systemctl status mbta_display.service` |
| View logs | `sudo journalctl -u mbta_display -n 100` |
| Find IP | `hostname -I` |
| Test API | `curl "https://api-v3.mbta.com/vehicles?api_key=YOUR_KEY"` |

### Common Issues
- **LEDs don't light**: Check wiring (GPIO 18, common ground)
- **Service won't start**: Check `.env` exists and API key is valid
- **Can't access web**: Try IP address instead of hostname

---

## What Gets Installed

### System Packages
- python3, python3-pip, python3-venv, python3-dev, git

### Python Packages (in venv)
- Flask, requests, sseclient, rpi-ws281x, adafruit-blinka, adafruit-circuitpython-neopixel, pytz

### Systemd Services
- `mbta_display.service` - Main display and web interface
- `mbta_monitor.service` - Health monitoring (auto-restarts main service)
- `daily_reboot.timer` - Daily 3 AM reboot for stability
- `wifi_configurator.service` *(optional, only with `--with-wifi-helper`)* - Captive-portal WiFi setup at boot

### Files Created
- `~/mbta_led_controller/.env` - Configuration
- `~/mbta_led_controller/venv/` - Python environment
- `~/mbta_led_controller/logs/` - Application logs
- `~/headless_wifi_helper/` *(optional)* - Cloned helper repo, used by `wifi_configurator.service`

---

## For Developers: Script Architecture

### Design Philosophy

Only 3 critical inputs required:
1. **MBTA API Key** - Cannot function without
2. **Line** - Which line to display (default: Red)
3. **Timezone** - For scheduling (default: Eastern)

All other settings have defaults and can be changed via web interface.

### Path Detection

```bash
ACTUAL_USER=${SUDO_USER:-$USER}
PROJECT_DIR=$(pwd)
VENV_PATH="$PROJECT_DIR/venv"
```

Service files updated dynamically via `sed`:
```bash
sed -i "s|WorkingDirectory=.*|WorkingDirectory=$PROJECT_DIR|g" deployment/systemd/*.service
```

### Why sudo Required
- Installs system packages
- Modifies timezone
- Copies files to `/etc/systemd/system/`
- Services need GPIO access

### Customization Points
- **Venv name**: Modify `VENV_NAME` variable
- **Defaults**: Change `${VAR:-default}` patterns
- **Validation**: Enhance with regex/pattern matching

---

## Additional Resources

- [Complete Setup Guide](../../docs/complete_setup_guide.md) - Manual setup
- [Operations & Troubleshooting](../../docs/operations_and_troubleshooting.md)
- [Hardware Assembly](../../docs/hardware_assembly_guide.md)
- [MBTA API Docs](https://api-v3.mbta.com/)
- [GPIO Pinout](https://pinout.xyz/)

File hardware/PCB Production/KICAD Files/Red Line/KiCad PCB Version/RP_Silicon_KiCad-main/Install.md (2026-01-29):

# Install KiCad libraries

## Manage Symbol Libraries

Accessed from the Preferences menu, add a new line with the +, give it a name and use the folder icon to point to the directory/folder where you have KiCadLibraries.

Manage Symbol Libraries screen shot


## Manage Footprint Libraries

Ditto! Accessed from the Preferences menu, add a new line with the +, give it a name and use the folder icon to point to the directory/folder where you have KiCadLibraries.

Manage Footprint Libraries screen shot


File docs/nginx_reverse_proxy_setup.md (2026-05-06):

# nginx Reverse Proxy Setup

Set up nginx so you can access the web interface at `http://hostname.local` instead of `http://hostname.local:8000`.

## Installation

### 1. Install nginx

```bash
sudo apt update
sudo apt install nginx -y
```

### 2. Create Configuration

```bash
sudo nano /etc/nginx/sites-available/mbta-display
```

Add:
```nginx
server {
    listen 80;
    listen [::]:80;
    server_name _;

    location / {
        proxy_pass http://127.0.0.1:8000;
        proxy_http_version 1.1;
        proxy_set_header Upgrade $http_upgrade;
        proxy_set_header Connection 'upgrade';
        proxy_set_header Host $host;
        proxy_set_header X-Real-IP $remote_addr;
        proxy_set_header X-Forwarded-For $proxy_add_x_forwarded_for;
        proxy_set_header X-Forwarded-Proto $scheme;
        proxy_connect_timeout 60s;
        proxy_send_timeout 60s;
        proxy_read_timeout 60s;
    }
}
```

### 3. Enable Configuration

```bash
sudo ln -s /etc/nginx/sites-available/mbta-display /etc/nginx/sites-enabled/
sudo rm /etc/nginx/sites-enabled/default
sudo nginx -t
```

Should show "syntax is ok" and "test is successful".

### 4. Start nginx

```bash
sudo systemctl enable nginx
sudo systemctl restart nginx
sudo systemctl status nginx
```

### 5. Verify

Access your display at `http://hostname.local` (no port needed).

## Optional: Pi Zero 2W Optimization

```bash
sudo nano /etc/nginx/nginx.conf
```

Set `worker_processes 1;` and add to `http` block:
```nginx
keepalive_timeout 15;
keepalive_requests 100;
client_body_buffer_size 10K;
client_header_buffer_size 1k;
client_max_body_size 8m;
large_client_header_buffers 2 1k;
```

Then: `sudo systemctl restart nginx`

## Coexistence with the headless WiFi helper

If you also installed [`tomunderwood99/headless_wifi_helper`](https://github.com/tomunderwood99/headless_wifi_helper)
via `setup_mbta_controller.sh --with-wifi-helper`, both services want port 80,
but on a normal boot they don't actually fight over it:

- The helper's captive portal binds to `192.168.4.1:80` (the AP gateway IP),
  not `0.0.0.0`, and only when `wifi_configurator.service` decides to bring
  the AP up because no known WiFi is in range.
- `wifi_configurator.service` is `Before=network-online.target`, and nginx
  effectively starts after `network-online.target` is reached. So while the
  captive portal is up, nginx is *not* running yet — no conflict.
- Once WiFi is up, the helper exits, the AP comes down, and nginx then binds
  port 80 on `0.0.0.0` (which includes wlan0's normal client IP).

The one case where they collide is if you manually start
`wifi_configurator.service` after the system is already up (e.g., for testing
the portal). nginx will already own port 80 on `0.0.0.0`, which includes
`192.168.4.1` once the AP comes up, and the portal will fail to bind with an
`OSError: [Errno 98] Address already in use` in `journalctl -u wifi_configurator`.
If you need to test the portal manually, stop nginx first:

```bash
sudo systemctl stop nginx
sudo systemctl start wifi_configurator.service
# When done:
sudo systemctl stop wifi_configurator.service
sudo systemctl start nginx
```

This is a manual-testing-only edge case; the normal boot path is conflict-free.

## Troubleshooting

| Problem | Check |
|---|---|
| nginx won't start | `sudo tail -f /var/log/nginx/error.log` |
| Can't access web | Is Flask running? `sudo netstat -tlnp \| grep 8000` |
| Port 80 in use | `sudo rm /etc/nginx/sites-enabled/default` |
| Config test fails | `sudo nginx -t` shows which line has error |
| `wifi_configurator` won't bind 80 | nginx already owns it — see [Coexistence](#coexistence-with-the-headless-wifi-helper) |

## Useful Commands

```bash
sudo systemctl restart nginx    # Restart
sudo systemctl reload nginx     # Reload config without downtime
sudo nginx -t                   # Test configuration
sudo tail -f /var/log/nginx/error.log   # View errors
sudo tail -f /var/log/nginx/access.log  # View access log
```

## Uninstalling

```bash
sudo systemctl stop nginx
sudo systemctl disable nginx
sudo apt remove nginx nginx-common -y
sudo apt autoremove -y
```

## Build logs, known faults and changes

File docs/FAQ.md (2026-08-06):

# Frequently Asked Questions (FAQ)

## General

### What is this project?
An open-source LED display system showing real-time MBTA train locations on a geographically accurate map. Each LED represents a station, lighting up to show where trains are.

### Do I need programming experience?
No. The automated setup script handles everything. If you can SSH into a Raspberry Pi, you can build this.

### How much does it cost?
**$50–200 USD** depending on components:
- Raspberry Pi Zero 2W: ~$15
- MicroSD Card (16GB): ~$8
- WS2812B LED Strip (~$15) or Custom PCB ($25–120)
- Power Supply (5V 4A): ~$10
- Frame & mounting: ~$10–20

See [Bill of Materials](bill_of_materials.md) for detailed pricing.

### How long does it take to build?
- **Hardware assembly**: 1–3 hours
- **Software setup**: 15–30 minutes (automated)

## Compatibility

### Can I use a different Raspberry Pi?
Yes. Tested on Pi Zero 2W, but should work on Pi 3/4/5. The original Pi Zero W may work but is slower.

### Can I adapt this for other transit systems?
Yes, with code modifications. See [Transit System Adaptation Guide](transit_system_adaptation_guide.md).

### Can I use different LEDs?
Designed for **WS2812B** (NeoPixel) addressable RGB LEDs. Other addressable types may work with code changes. Regular non-addressable LEDs won't work.

## Hardware

### Do I need the custom PCB?
No. You can use a standard WS2812B LED strip (cheaper, good for prototyping) or order the custom PCB (cleaner look, geographically accurate).

### My LEDs aren't lighting up
See [Operations & Troubleshooting](operations_and_troubleshooting.md#leds-dont-light-up) for a complete checklist.

### Can I power Pi and LEDs from the same supply?
Yes. A 5V 4A USB-C supply can power both. Must share common ground.

## Software

### Does this need WiFi?
Yes—for API data streaming and SSH access.

### What happens if internet goes down?
Display shows all red LEDs indicating connection issue. Automatically reconnects when internet returns.

### Do I need an MBTA API key?
Yes, but it's **free**: [api-v3.mbta.com](https://api-v3.mbta.com/)

### Can I access the web interface remotely?
Not by default. Options:
1. **Raspberry Pi Connect** (easiest)
2. **VPN** (Tailscale, WireGuard)
3. **Reverse proxy** (Cloudflare Tunnel, ngrok)

### How do I update the software?
```bash
cd ~/mbta_led_controller
git pull
sudo systemctl restart mbta_display.service
```

## Display Modes

### What do the different modes show?
- **Vehicles**: Train positions (stopped, approaching, in transit)
- **Speed**: Train speeds (green=slow/stopped, red=fast, blue=unknown). Green Line uses API speed (m/s→mph); Red/Blue/Orange estimate from GPS when API speed is null.
- **Occupancy**: Crowding levels — data limited
- **Rainbow**: Animated rainbow for testing/decoration

### What is bedtime mode?
Automatically turns off display during specified hours (e.g., 10 PM – 6 AM). Configurable via web interface.

### How often does the display update?
Real-time via MBTA API stream—typically every few seconds.

## Troubleshooting

For detailed troubleshooting, see [Operations & Troubleshooting](operations_and_troubleshooting.md).

## Other

### Is this project maintained?
Check the GitHub repository for recent activity.

### Can I sell displays built with this?
The **software** is under the MIT License ([LICENSE](../LICENSE)). **PCB and hardware design files** in `hardware/` are under CERN-OHL-S ([LICENSE-CERN-OHL-S](../LICENSE-CERN-OHL-S)); if you distribute or sell products built from those designs, follow that license’s requirements. Please credit the project where reasonable and respect the MBTA API terms of service.

### Does the MBTA endorse this?
No. This is an independent project using publicly available MBTA data.

### Can I share my build?
Absolutely! Tag and share on social media—I'd love to see your builds.

**Still have questions?** Open an issue on GitHub.

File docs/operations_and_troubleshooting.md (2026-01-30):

# Operations and Troubleshooting Guide

Day-to-day operations and troubleshooting for the MBTA LED Controller.

## Service Management

### Control Commands

```bash
sudo systemctl <command> mbta_display.service
sudo systemctl <command> mbta_monitor.service
```

| Command | Description |
|---|---|
| `start` | Start service |
| `stop` | Stop service |
| `restart` | Restart (use after config changes) |
| `status` | Check if running |
| `enable` | Auto-start on boot |
| `disable` | Disable auto-start |

### Viewing Logs

```bash
# Live logs
sudo journalctl -u mbta_display -f

# Last 100 lines
sudo journalctl -u mbta_display -n 100

# Today's logs
sudo journalctl -u mbta_display --since today

# Errors only
sudo journalctl -u mbta_display -p err

# Application logs
tail -f ~/mbta_led_controller/logs/mbta_display.log
```

### Configuration Changes

```bash
nano ~/mbta_led_controller/.env
sudo systemctl restart mbta_display.service
```

Most settings can also be changed via the web interface without restart.

## Troubleshooting

### LEDs Don't Light Up

**1. Test with red_test.py:**
```bash
cd ~/mbta_led_controller
source venv/bin/activate
sudo -E venv/bin/python tests/red_test.py
```

**2. Check wiring:**
- Data wire → GPIO 18 (physical pin 12)
- Ground from Pi → LED power supply ground (shared ground required)
- LEDs have 5V power supply (not from Pi's 5V pin)
- Data wire is first in chain (check LED strip direction arrows)

**3. Check settings:**
- Power not set to "off" in web interface
- Not in bedtime hours
- Brightness not set to 0

**Note on logic level shifters:** Generally not needed for WS2812B-2020 LEDs with shared power supply. See [Adafruit NeoPixel Guide](https://learn.adafruit.com/adafruit-neopixel-uberguide/powering-neopixels) for details.

### Service Won't Start

```bash
# Check status for error details
sudo systemctl status mbta_display.service

# View recent logs
sudo journalctl -u mbta_display -n 50
```

**Common causes:**
- Wrong paths in service file (verify username/paths match)
- Missing `.env` file in project root
- Invalid MBTA API key

### Network/API Issues

```bash
# Test API connectivity (replace YOUR_API_KEY)
curl -s "https://api-v3.mbta.com/vehicles?api_key=YOUR_API_KEY&filter[route]=Red" | head -c 200

# Check for connection errors
sudo journalctl -u mbta_display -p err
```

### Web Interface Not Accessible

```bash
# Check service status
sudo systemctl status mbta_display.service

# Check if port 8000 is listening
sudo netstat -tlnp | grep 8000

# Test locally
curl http://localhost:8000
```

**Also verify:**
- You're on the same network as the Pi
- Try IP address instead of hostname: `http://192.168.x.x:8000`

### Settings Not Saving

```bash
# Check .env file location and permissions
ls -la ~/mbta_led_controller/.env

# View application logs for errors
tail -f ~/mbta_led_controller/logs/*.log
```

## Quick Reference

| Task | Command |
|---|---|
| Check status | `display_status` or `sudo systemctl status mbta_display` |
| Restart display | `sudo systemctl restart mbta_display.service` |
| View live logs | `sudo journalctl -u mbta_display -f` |
| Edit config | `nano ~/mbta_led_controller/.env` |
| Test LEDs | `sudo -E venv/bin/python tests/red_test.py` |
| Find Pi's IP | `hostname -I` |

## Additional Resources

- [Complete Setup Guide](complete_setup_guide.md) - Full installation instructions
- [Hardware Assembly Guide](hardware_assembly_guide.md) - Wiring and assembly
- [FAQ](FAQ.md) - Common questions
- [GitHub Issues](https://github.com/tomunderwood99/CharlieBoard/issues) - Report bugs

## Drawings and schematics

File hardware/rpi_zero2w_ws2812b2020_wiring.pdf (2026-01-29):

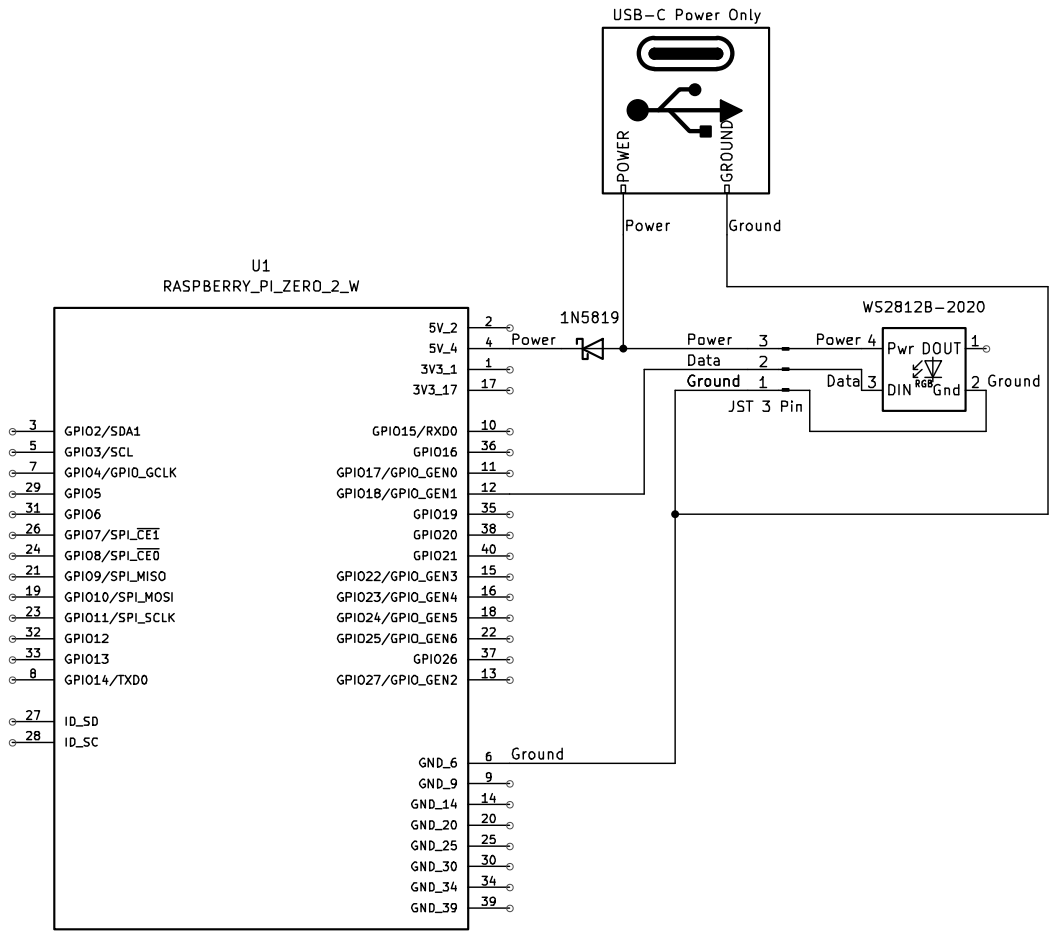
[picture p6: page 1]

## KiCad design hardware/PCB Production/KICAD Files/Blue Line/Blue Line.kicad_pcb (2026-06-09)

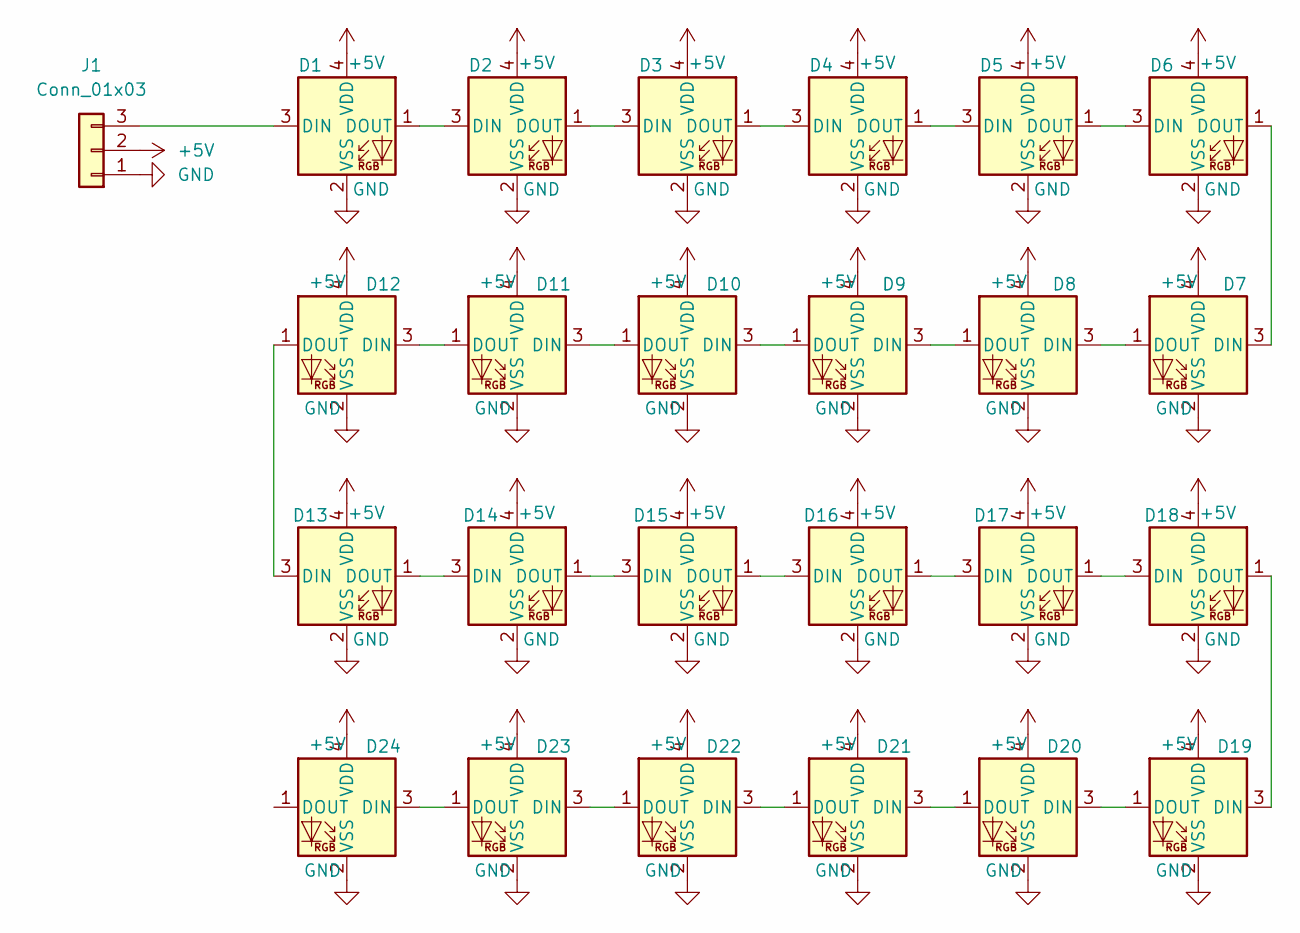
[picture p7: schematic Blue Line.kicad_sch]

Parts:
D1, D2, D3, D4, D5, D6, D7, D8, D9, D10, D11, D12, D13, D14, D15, D16, D17, D18, D19, D20, D21, D22, D23, D24: WS2812B-2020; LED_WS2812B-2020_PLCC4_2.0x2.0mm; LCSC C965555
J1: Conn_01x03; CONN3_S3B-PH_JST

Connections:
+5V: D1.4 (VDD), D2.4 (VDD), D3.4 (VDD), D4.4 (VDD), D5.4 (VDD), D6.4 (VDD), D7.4 (VDD), D8.4 (VDD), D9.4 (VDD), D10.4 (VDD), D11.4 (VDD), D12.4 (VDD), D13.4 (VDD), D14.4 (VDD), D15.4 (VDD), D16.4 (VDD), D17.4 (VDD), D18.4 (VDD), D19.4 (VDD), D20.4 (VDD), D21.4 (VDD), D22.4 (VDD), D23.4 (VDD), D24.4 (VDD), J1.2
GND: D1.2 (VSS), D2.2 (VSS), D3.2 (VSS), D4.2 (VSS), D5.2 (VSS), D6.2 (VSS), D7.2 (VSS), D8.2 (VSS), D9.2 (VSS), D10.2 (VSS), D11.2 (VSS), D12.2 (VSS), D13.2 (VSS), D14.2 (VSS), D15.2 (VSS), D16.2 (VSS), D17.2 (VSS), D18.2 (VSS), D19.2 (VSS), D20.2 (VSS), D21.2 (VSS), D22.2 (VSS), D23.2 (VSS), D24.2 (VSS), J1.1
unnamed: D1.3 (DIN), J1.3
unnamed: D1.1 (DOUT), D2.3 (DIN)
unnamed: D2.1 (DOUT), D3.3 (DIN)
unnamed: D3.1 (DOUT), D4.3 (DIN)
unnamed: D4.1 (DOUT), D5.3 (DIN)
unnamed: D5.1 (DOUT), D6.3 (DIN)
unnamed: D6.1 (DOUT), D7.3 (DIN)
unnamed: D7.1 (DOUT), D8.3 (DIN)
unnamed: D8.1 (DOUT), D9.3 (DIN)
unnamed: D9.1 (DOUT), D10.3 (DIN)
unnamed: D10.1 (DOUT), D11.3 (DIN)
unnamed: D11.1 (DOUT), D12.3 (DIN)
unnamed: D12.1 (DOUT), D13.3 (DIN)
unnamed: D13.1 (DOUT), D14.3 (DIN)
unnamed: D14.1 (DOUT), D15.3 (DIN)
unnamed: D15.1 (DOUT), D16.3 (DIN)
unnamed: D16.1 (DOUT), D17.3 (DIN)
unnamed: D17.1 (DOUT), D18.3 (DIN)
unnamed: D18.1 (DOUT), D19.3 (DIN)
unnamed: D19.1 (DOUT), D20.3 (DIN)
unnamed: D20.1 (DOUT), D21.3 (DIN)
unnamed: D21.1 (DOUT), D22.3 (DIN)
unnamed: D22.1 (DOUT), D23.3 (DIN)
unnamed: D23.1 (DOUT), D24.3 (DIN)

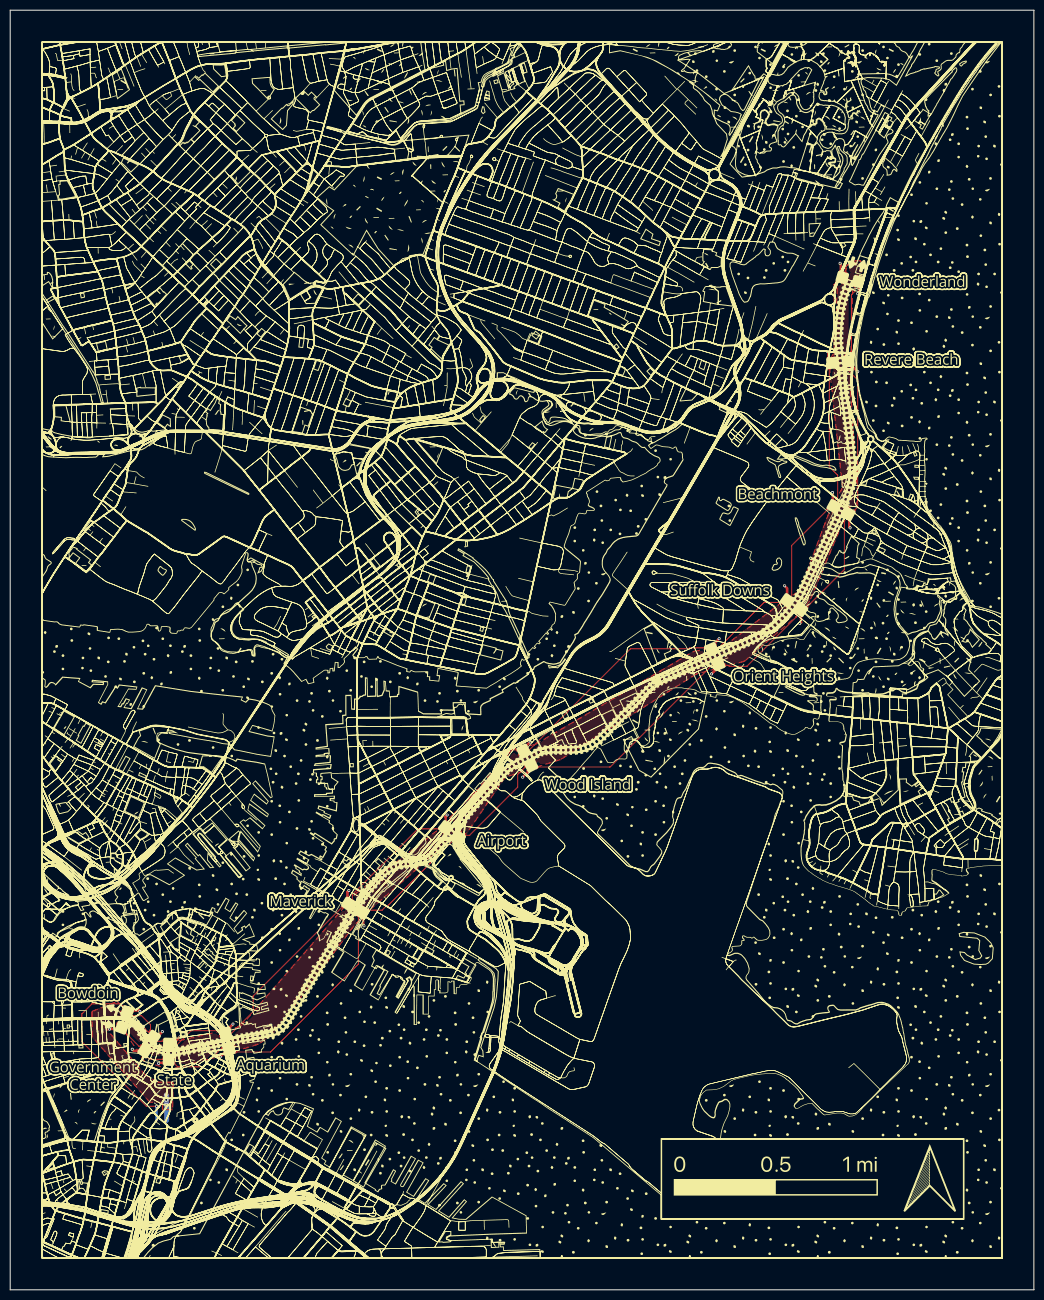
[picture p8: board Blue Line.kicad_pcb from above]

Board: 2 copper layers, 203.2 x 254.0 mm, 25 parts (1 on the bottom side), 26 nets.

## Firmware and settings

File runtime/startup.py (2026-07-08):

#!/usr/bin/env python3
import subprocess
import sys
import os
import signal
import time
import logging
import traceback
import json
from datetime import datetime, timedelta
from logging.handlers import RotatingFileHandler

# Add project root to path for imports
script_dir = os.path.dirname(os.path.abspath(__file__))
project_dir = os.path.dirname(script_dir)
if project_dir not in sys.path:
    sys.path.insert(0, project_dir)

from config.constants import (
    LOG_FILE_MAX_BYTES,
    LOG_FILE_BACKUP_COUNT,
    MAX_REBOOTS,
    REBOOT_DELAY_SECONDS,
    REBOOT_WINDOW_HOURS,
    DEFAULT_LED_COUNT,
    LED_COUNT_ADJUSTMENT,
    SAFE_MODE_BRIGHTNESS,
    SAFE_MODE_COLOR,
    SAFE_MODE_REFRESH_INTERVAL_SECONDS,
    WEB_INTERFACE_STARTUP_DELAY_SECONDS,
    LED_CONTROLLER_STARTUP_DELAY_SECONDS,
    PROCESS_TERMINATE_TIMEOUT_SECONDS,
    MONITOR_LOOP_INTERVAL_SECONDS,
)

# Configure logging
# Note: No StreamHandler - when running via systemd, stdout is captured by journalctl
os.makedirs('logs', exist_ok=True)
logging.basicConfig(
    level=logging.INFO,
    format='%(asctime)s - %(name)s - %(levelname)s - %(message)s',
    handlers=[
        RotatingFileHandler(
            'logs/startup.log',
            maxBytes=LOG_FILE_MAX_BYTES,
            backupCount=LOG_FILE_BACKUP_COUNT,
            encoding='utf-8'
        )
    ]
)
logger = logging.getLogger(__name__)

# Reboot loop protection file path
REBOOT_COUNTER_FILE = 'logs/reboot_counter.json'


def get_reboot_count() -> int:
    """Get the current reboot count from the counter file.
    
    Returns:
        int: Number of reboots within the time window, or 0 if counter is stale/missing
    """
    try:
        if not os.path.exists(REBOOT_COUNTER_FILE):
            return 0
        
        with open(REBOOT_COUNTER_FILE, 'r') as f:
            data = json.load(f)
        
        # Check if the counter is within the time window
        last_reboot_time = datetime.fromisoformat(data.get('last_reboot_time', ''))
        if datetime.now() - last_reboot_time > timedelta(hours=REBOOT_WINDOW_HOURS):
            # Counter is stale, reset it
            logger.info(f"Reboot counter expired (last reboot was {last_reboot_time}), resetting to 0")
            reset_reboot_count()
            return 0
        
        return data.get('count', 0)
    except Exception as e:
        logger.warning(f"Failed to read reboot counter: {e}")
        return 0


def increment_reboot_count() -> int:
    """Increment the reboot counter and return the new count.
    
    Returns:
        int: The new reboot count after incrementing
    """
    try:
        current_count = get_reboot_count()
        new_count = current_count + 1
        
        data = {
            'count': new_count,
            'last_reboot_time': datetime.now().isoformat()
        }
        
        with open(REBOOT_COUNTER_FILE, 'w') as f:
            json.dump(data, f, indent=2)
        
        logger.info(f"Reboot counter incremented to {new_count}/{MAX_REBOOTS}")
        return new_count
    except Exception as e:
        logger.error(f"Failed to increment reboot counter: {e}")
        return MAX_REBOOTS + 1  # Return high value to trigger safe mode on error


def reset_reboot_count() -> None:
    """Reset the reboot counter to 0."""
    try:
        if os.path.exists(REBOOT_COUNTER_FILE):
            os.remove(REBOOT_COUNTER_FILE)
            logger.info("Reboot counter reset")
    except Exception as e:
        logger.warning(f"Failed to reset reboot counter: {e}")


def set_leds_blue_fallback() -> None:
    """Set all LEDs to blue as a fallback when max reboots reached.
    
    This function attempts to directly control the LEDs without going through
    the full application stack, as a visual indicator that safe mode is active.
    """
    try:
        import board
        import neopixel
        
        # Try to determine LED count from config, fallback to reasonable default
        led_count = DEFAULT_LED_COUNT  # Default fallback
        try:
            from config.station_led_maps import station_led_maps
            # Get LED count from Red line as default
            outbound_map, inbound_map = station_led_maps.get('Red', (lambda: ({}, {})))()
            if outbound_map or inbound_map:
                led_count = max(
                    max(outbound_map.values()) if outbound_map else 0,
                    max(inbound_map.values()) if inbound_map else 0
                ) + LED_COUNT_ADJUSTMENT  # +1 for 0-indexing, +3 for color key
        except Exception:
            pass  # Use default LED count
        
        logger.info(f"Setting {led_count} LEDs to blue (safe mode indicator)")
        
        pixels = neopixel.NeoPixel(
            board.D18,
            led_count,
            brightness=SAFE_MODE_BRIGHTNESS,  # User-scale; hardware level set by BRIGHTNESS_MULTIPLIER
            auto_write=False,
            pixel_order=neopixel.GRB
        )
        
        # Set all LEDs to blue
        pixels.fill(SAFE_MODE_COLOR)
        pixels.show()
        
        logger.info("LEDs set to blue successfully")
    except Exception as e:
        logger.error(f"Failed to set LEDs to blue: {e}")


def safe_mode_wait() -> None:
    """Enter safe mode: set LEDs blue and wait indefinitely.
    
    This prevents reboot loops by stopping all restart attempts and
    providing a visual indicator (blue LEDs) that intervention is needed.
    """
    logger.critical(f"SAFE MODE: Maximum reboots ({MAX_REBOOTS}) reached within {REBOOT_WINDOW_HOURS} hour(s)")
    logger.critical("System is in safe mode. Manual intervention required.")
    logger.critical("To exit safe mode: 1) Fix the issue, 2) Delete logs/reboot_counter.json, 3) Reboot manually")
    
    set_leds_blue_fallback()
    
    # Wait indefinitely - system will stay in this state until manual intervention
    logger.info("Entering infinite wait. System requires manual reboot after fixing the issue.")
    while True:
        time.sleep(SAFE_MODE_REFRESH_INTERVAL_SECONDS)
        # Periodically refresh the blue LEDs in case they reset
        set_leds_blue_fallback()


def log_detailed_error(name: str, process, error: Exception = None) -> None:
    """Log detailed error information including process output and stack trace."""
    try:
        timestamp = datetime.now().strftime("%Y%m%d_%H%M%S")
        error_log_path = f'logs/error_{timestamp}.log'
        
        with open(error_log_path, 'w') as f:
            # Write error header
            f.write(f"=== Error Report for {name} ===\n")
            f.write(f"Timestamp: {timestamp}\n")
            f.write(f"Process: {name}\n")
            if process:
                f.write(f"PID: {process.pid}\n")
                f.write(f"Return Code: {process.poll()}\n\n")
            
            # Write exception info if available
            if error:
                f.write("=== Exception Details ===\n")
                f.write(f"Error Type: {type(error).__name__}\n")
                f.write(f"Error Message: {str(error)}\n")
                f.write("Stack Trace:\n")
                f.write(traceback.format_exc())
                f.write("\n")
            
            # Write process output
            if process:
                f.write("=== Process Output ===\n")
                f.write("STDOUT:\n")
                stdout, stderr = process.communicate()
                if stdout:
                    f.write(stdout)
                f.write("\nSTDERR:\n")
                if stderr:
                    f.write(stderr)
        
        logger.error(f"Detailed error log written to {error_log_path}")
    except Exception as e:
        logger.error(f"Failed to write detailed error log: {e}")

def system_reboot() -> bool:
    """Initiate system reboot with loop protection.
    
    Checks the reboot counter before rebooting. If max reboots reached,
    enters safe mode instead.
    
    Returns:
        bool: True if reboot was initiated, False if safe mode was entered
    """
    # Check reboot counter first
    reboot_count = increment_reboot_count()
    
    if reboot_count > MAX_REBOOTS:
        logger.warning(f"Reboot count ({reboot_count}) exceeds maximum ({MAX_REBOOTS})")
        safe_mode_wait()
        return False  # Will never reach here due to infinite loop in safe_mode_wait
    
    # Delay before reboot to prevent rapid reboot loops
    logger.info(f"Waiting {REBOOT_DELAY_SECONDS} seconds before reboot (attempt {reboot_count}/{MAX_REBOOTS})...")
    time.sleep(REBOOT_DELAY_SECONDS)
    
    try:
        logger.info("Initiating system reboot...")
        # Check if running as root
        if os.geteuid() == 0:
            subprocess.run(['shutdown', '-r', 'now'], check=True)
        else:
            subprocess.run(['sudo', 'shutdown', '-r', 'now'], check=True)
        return True
    except subprocess.CalledProcessError as e:
        logger.error(f"Failed to initiate reboot: {e}")
        return False
    except Exception as e:
        logger.error(f"Unexpected error during reboot: {e}")
        return False

def start_process(command, name):
    """Start a process and return its subprocess.Popen object."""
    try:
        # Get the directory of the current script and its parent
        startup_script_dir = os.path.dirname(os.path.abspath(__file__))
        startup_project_dir = os.path.dirname(startup_script_dir)
        
        # Start the process
        process = subprocess.Popen(
            command,
            cwd=startup_project_dir,  # Run from project root directory
            stdout=subprocess.PIPE,
            stderr=subprocess.PIPE,
            universal_newlines=True,
            bufsize=1,  # Line buffered
            # Add these for better process management
            preexec_fn=os.setsid,  # Create new process group
            close_fds=True
        )
        
        logger.info(f"Started {name} (PID: {process.pid})")
        return process
    except Exception as e:
        logger.error(f"Failed to start {name}: {e}")
        log_detailed_error(name, None, e)
        return None

def monitor_output(process, name, quiet_mode=False):
    """Monitor a process's output in a non-blocking way."""
    try:
        # Use non-blocking reads with timeout
        import select
        
        # Check stdout
        if process.stdout and select.select([process.stdout], [], [], 0.0)[0]:
            line = process.stdout.readline()
            if line:
                # In quiet mode, only log important messages
                if not quiet_mode or any(keyword in line.lower() for keyword in ['error', 'warning', 'critical', 'failed', 'exception']):
                    logger.info(f"{name} output: {line.strip()}")
        
        # Check stderr
        if process.stderr and select.select([process.stderr], [], [], 0.0)[0]:
            line = process.stderr.readline()
            if line:
                # Filter out routine INFO messages that aren't actual errors
                line_lower = line.lower()
                if any(keyword in line_lower for keyword in ['error', 'warning', 'critical', 'failed', 'exception', 'traceback']):
                    logger.error(f"{name} error: {line.strip()}")
                elif any(keyword in line_lower for keyword in ['settings loaded successfully', 'settings saved successfully', 'settings file modified', 'forcing settings reload', 'updated bedtime']):
                    # These are routine INFO messages, not errors - log at debug level or skip
                    if not quiet_mode:
                        logger.debug(f"{name} info: {line.strip()}")
                elif any(keyword in line_lower for keyword in ['serving flask app', 'development server', 'production deployment', 'werkzeug', 'flask']):
                    # These are Flask startup messages, not errors - log at debug level or skip
                    if not quiet_mode:
                        logger.debug(f"{name} flask: {line.strip()}")
                else:
                    # Other stderr messages - log as warnings in case they're important
                    if not quiet_mode:
                        logger.warning(f"{name} stderr: {line.strip()}")
    except Exception as e:
        logger.warning(f"Error monitoring {name} output: {e}")

def check_process_health(process, name):
    """Check if a process is healthy without blocking."""
    if process.poll() is not None:
        return False, f"Process {name} has stopped (return code: {process.poll()})"
    
    # Check if process is responsive by sending a signal 0
    try:
        os.kill(process.pid, 0)
        return True, None
    except OSError:
        return False, f"Process {name} is not responding"

def cleanup_processes(processes):
    """Cleanup processes on shutdown."""
    for name, process in processes.items():
        if process and process.poll() is None:  # If process is still running
            logger.info(f"Stopping {name}...")
            process.terminate()
            try:
                process.wait(timeout=PROCESS_TERMINATE_TIMEOUT_SECONDS)  # Wait up to 5 seconds
            except subprocess.TimeoutExpired:
                logger.warning(f"{name} didn't terminate, forcing...")
                process.kill()  # Force kill if it doesn't terminate
            logger.info(f"Stopped {name}")

def main():
    """Main function to start and monitor all processes."""
    processes = {}
    startup_complete = False
    
    try:
        # Start web interface
        web_process = start_process(
            [sys.executable, 'web_interface/app.py'],
            'Web Interface'
        )
        if web_process:
            processes['Web Interface'] = web_process
        else:
            raise Exception("Failed to start Web Interface")
        
        # Give web interface a moment to start
        time.sleep(WEB_INTERFACE_STARTUP_DELAY_SECONDS)
        
        # Start LED controller
        controller_process = start_process(
            [sys.executable, 'main/mbta_stream.py'],
            'LED Controller'
        )
        if controller_process:
            processes['LED Controller'] = controller_process
        else:
            raise Exception("Failed to start LED Controller")
        
        # Wait a bit more for initial startup messages
        time.sleep(LED_CONTROLLER_STARTUP_DELAY_SECONDS)
        
        # Mark startup as complete and start quiet mode
        startup_complete = True
        logger.info("Startup complete - entering quiet mode (only errors and warnings will be logged)")
        
        # Reset reboot counter after successful startup
        # This indicates the system is stable and any previous issues are resolved
        reset_reboot_count()
        
        # Monitor processes
        while True:
            # Check if either process has ended
            for name, process in processes.items():
                # Use the new health check function
                is_healthy, error_msg = check_process_health(process, name)
                if not is_healthy:
                    logger.error(error_msg)
                    log_detailed_error(name, process)
                    cleanup_processes(processes)
                    logger.info("Initiating system reboot...")
                    system_reboot()
                    sys.exit(1)  # Exit in case reboot fails
                
                # Monitor output (non-blocking) - use quiet mode after startup
                monitor_output(process, name, quiet_mode=startup_complete)
            
            time.sleep(MONITOR_LOOP_INTERVAL_SECONDS)  # Check every second instead of every 0.1 seconds
            
    except KeyboardInterrupt:
        logger.info("Received shutdown signal...")
    except Exception as e:
        logger.error(f"Error in main loop: {e}")
        # Log detailed error for the failed process
        for name, process in processes.items():
            if process.poll() is not None:
                log_detailed_error(name, process, e)
        cleanup_processes(processes)
        logger.info("Initiating system reboot...")
        system_reboot()
        sys.exit(1)  # Exit in case reboot fails
    finally:
        cleanup_processes(processes)
        logger.info("Shutdown complete")

if __name__ == "__main__":
    # Handle SIGTERM gracefully
    signal.signal(signal.SIGTERM, lambda signo, frame: sys.exit(0))
    main() 

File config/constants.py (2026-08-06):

"""
Centralized constants for the MBTA LED Controller.

This module contains all magic numbers and configuration constants used throughout
the application. Grouping them here makes the codebase easier to maintain and tune.
"""

# =============================================================================
# TIME CONSTANTS
# =============================================================================

# MBTA quiet hours (when train service is minimal/stopped)
MBTA_QUIET_HOURS_START = 0   # 12:00 AM (midnight)
MBTA_QUIET_HOURS_END = 6     # 6:00 AM

# Default bedtime settings (when display turns off)
DEFAULT_BEDTIME_START_HOUR = 22  # 10:00 PM
DEFAULT_BEDTIME_START_MINUTE = 0
DEFAULT_BEDTIME_END_HOUR = 6     # 6:00 AM
DEFAULT_BEDTIME_END_MINUTE = 0

# =============================================================================
# COLOR CONSTANTS
# =============================================================================

# RGB color value bounds
COLOR_MIN = 0
COLOR_MAX = 255
RGB_CHANNELS = 3  # Number of color channels (R, G, B)

# LED off color
LED_OFF = (0, 0, 0)

# Network status indicator colors
NETWORK_DISCONNECTED_COLOR = (255, 0, 0)   # Red
NETWORK_RECONNECTING_COLOR = (0, 0, 255)   # Blue

# Safe mode indicator color (used when max reboots reached)
SAFE_MODE_COLOR = (0, 0, 255)  # Blue

# =============================================================================
# BRIGHTNESS CONSTANTS
# =============================================================================

BRIGHTNESS_MIN = 0.0
BRIGHTNESS_MAX = 1.0  # User/settings scale (slider, .env, validation)
DEFAULT_BRIGHTNESS = 1.0
# Scales user brightness to NeoPixel hardware (1.0 slider * 0.3 ≈ prior "full" feel at 30%)
BRIGHTNESS_MULTIPLIER = 0.3
SAFE_MODE_BRIGHTNESS = 1.0  # User scale; same ~30% hardware as old 0.3 with BRIGHTNESS_MULTIPLIER

# =============================================================================
# HARDWARE CONSTANTS
# =============================================================================

# GPIO pin for NeoPixel LED strip (Raspberry Pi)
LED_GPIO_PIN = 18  # board.D18

# Default fallback LED count (used when config unavailable)
DEFAULT_LED_COUNT = 100

# Color key LED count (LEDs at end of strip showing color legend)
COLOR_KEY_LED_COUNT = 3

# LED count adjustment for 0-indexing (+1) and color key (+3)
LED_COUNT_ADJUSTMENT = 4

# =============================================================================
# DISPLAY MODE CONSTANTS
# =============================================================================

# Rainbow mode animation
RAINBOW_ANIMATION_SPEED = 5
RAINBOW_WHEEL_POSITIONS = 256
RAINBOW_WHEEL_SEGMENT_1 = 85   # First color transition boundary
RAINBOW_WHEEL_SEGMENT_2 = 170  # Second color transition boundary
RAINBOW_WHEEL_MULTIPLIER = 3   # Color intensity multiplier

# Speed mode
# MBTA attributes.speed is meters/second when present; convert before display.
MS_TO_MPH = 2.2369362921

# Per-line color ceilings / spike caps (mph). Orange tops out higher than Red/Blue.
LINE_MAX_SPEED_MPH = {
    "Red": 50,
    "Blue": 50,
    "Orange": 55,
    "Green-B": 50,
    "Green-C": 50,
    "Green-D": 50,
    "Green-E": 50,
}
# Fallback when route is unknown (also used by legacy imports)
MAX_VEHICLE_SPEED_MPH = 50

# GPS speed-from-position estimator (SSE-driven Δt, not a poll interval)
SPEED_ESTIMATE_MIN_DT_S = 2.0
SPEED_ESTIMATE_MAX_DT_S = 45.0
SPEED_EMA_ALPHA = 0.35
SPEED_SPIKE_FACTOR = 1.25

# Occupancy mode
MAX_OCCUPANCY_PERCENTAGE = 100

# =============================================================================
# ERROR HANDLING CONSTANTS
# =============================================================================

# Maximum consecutive errors before suppressing detailed logs
MAX_CONSECUTIVE_ERRORS = 5

# Seconds between detailed error logs when errors persist
ERROR_LOG_COOLDOWN_SECONDS = 30

# Maximum age in days for error data files before cleanup
ERROR_FILE_MAX_AGE_DAYS = 7

# String preview lengths for error logging
ERROR_DATA_PREVIEW_LENGTH = 500   # Full error data preview
ERROR_LOG_PREVIEW_LENGTH = 100    # Short error preview in logs

# =============================================================================
# LOGGING BEHAVIOR CONSTANTS
# =============================================================================

# How often to log health status (every N events)
HEALTH_LOG_FREQUENCY = 10

# =============================================================================
# SSE STREAM CONSTANTS
# =============================================================================

# Chunk size for SSE client (handles large reset events)
SSE_CHUNK_SIZE = 65536  # 64KB

# =============================================================================
# HEALTH MONITORING CONSTANTS
# =============================================================================
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

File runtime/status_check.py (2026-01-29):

#!/usr/bin/env python3
"""
MBTA LED Controller Status Checker
Quick command to check system status and display information
"""

import sys
import os
import json
import time
from datetime import datetime

def get_project_root():
    """Get the project root directory based on this script's location."""
    # This script is in runtime/status_check.py, so go up one level to get project root
    script_dir = os.path.dirname(os.path.abspath(__file__))
    project_root = os.path.dirname(script_dir)
    return project_root

# Add project root to path for imports
_project_root = get_project_root()
if _project_root not in sys.path:
    sys.path.insert(0, _project_root)

from monitoring.system_utils import format_uptime
from config.constants import (
    METRICS_FILE_MAX_AGE_SECONDS,
    STATUS_DISPLAY_WIDTH,
    CPU_TEMPERATURE_HOT_THRESHOLD,
    CPU_TEMPERATURE_WARM_THRESHOLD,
    MEMORY_CRITICAL_THRESHOLD_PERCENT,
    MEMORY_HIGH_THRESHOLD_PERCENT,
)


def get_ascii_art():
    """Return the specified ASCII art."""
    return ""

def get_system_status():
    """Get current system status from metrics file directly."""
    try:
        project_root = get_project_root()
        
        # Read metrics file directly to avoid import issues
        metrics_file = os.path.join(project_root, 'logs', 'metrics.json')
        if not os.path.exists(metrics_file):
            return {
                'error': 'Metrics file not found - system may not be running',
                'healthy': False,
                'active_vehicles': 0,
                'display_mode': 'unknown',
                'uptime': 0
            }
        
        # Check if metrics file is stale (older than 2 minutes)
        file_age = time.time() - os.path.getmtime(metrics_file)
        metrics_stale = file_age > METRICS_FILE_MAX_AGE_SECONDS  # 2 minutes
        
        with open(metrics_file, 'r') as f:
            metrics_data = json.load(f)
        
        # Extract relevant information
        health_status = metrics_data.get('health', {})
        performance_metrics = metrics_data.get('performance', {})
        
        # Get current settings from .env file
        current_mode = 'unknown'
        last_settings_mod = 'unknown'
        env_file = os.path.join(project_root, '.env')
        if os.path.exists(env_file):
            try:
                # Get last modification time
                last_mod_time = os.path.getmtime(env_file)
                last_settings_mod = datetime.fromtimestamp(last_mod_time).strftime('%Y-%m-%d %H:%M:%S')
                
                # Read display mode
                with open(env_file, 'r') as f:
                    for line in f:
                        line = line.strip()
                        if line.startswith('DISPLAY_MODE='):
                            current_mode = line.split('=', 1)[1].strip('"\'')
                            break
            except:
                pass
        
        return {
            'healthy': health_status.get('healthy', False),
            'active_vehicles': health_status.get('active_vehicles', 0),
            'display_mode': current_mode,
            'session_uptime': health_status.get('session_uptime_seconds', 0),
            'total_uptime': health_status.get('total_uptime_seconds', 0),
            'session_start_time': health_status.get('session_start_time', 'unknown'),
            'first_start_time': health_status.get('first_start_time', 'unknown'),
            'last_led_update': health_status.get('last_led_update', 'unknown'),
            'last_settings_mod': last_settings_mod,
            'api_healthy': health_status.get('api_healthy', False),
            'led_healthy': health_status.get('led_healthy', False),
            'metrics_stale': metrics_stale,
            'metrics_age_seconds': int(file_age),
            'memory_usage': health_status.get('memory_usage'),
            'cpu_temperature': health_status.get('cpu_temperature')
        }
    except Exception as e:
        return {
            'error': str(e),
            'healthy': False,
            'active_vehicles': 0,
            'display_mode': 'unknown',
            'session_uptime': 0,
            'total_uptime': 0
        }
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

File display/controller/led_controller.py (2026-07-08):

import board
import neopixel
from typing import List, Tuple
from config.bedtime import BedtimeManager
from config.constants import (
    NETWORK_DISCONNECTED_COLOR,
    NETWORK_RECONNECTING_COLOR,
    LED_OFF,
    BRIGHTNESS_MIN,
    BRIGHTNESS_MAX,
    BRIGHTNESS_MULTIPLIER,
)
import logging

logger = logging.getLogger(__name__)

class LEDController:
    """Controls the physical LED strip display."""
    
    def __init__(self, led_count: int, color_key_count: int = 3, brightness: float = 1.0, power_state: str = 'off',
                 bedtime_start: str = "22:00", bedtime_end: str = "06:00", metrics=None):
        """Initialize the LED controller.
        
        Args:
            led_count: Number of LEDs for train display
            color_key_count: Number of LEDs used for color key
            brightness: Initial brightness on user scale (0.0 to 1.0, before BRIGHTNESS_MULTIPLIER)
            power_state: Initial power state ('on' or 'off')
            bedtime_start: Time to turn off display (24-hour format "HH:MM")
            bedtime_end: Time to turn on display (24-hour format "HH:MM")
            metrics: Optional SystemMetrics instance for tracking LED updates
        """
        self.led_count = led_count
        self.color_key_count = color_key_count
        self.total_leds = led_count + color_key_count
        self.user_power_state = power_state == 'on'
        self._last_colors = [LED_OFF] * self.led_count
        self._last_color_key = [LED_OFF] * self.color_key_count
        self._network_status = 'connected'
        self.metrics = metrics
        
        # Initialize bedtime manager
        self.bedtime_manager = BedtimeManager(bedtime_start, bedtime_end)
        
        # Initialize the LED strip
        self.pixels = neopixel.NeoPixel(
            board.D18,  # GPIO pin
            self.total_leds,
            brightness=self._hardware_brightness(brightness),
            auto_write=False,
            pixel_order=neopixel.GRB
        )
        
        # Turn off all LEDs initially
        self.clear_display()
    
    def is_display_on(self) -> bool:
        """Check if display should be on based on power state and bedtime.
        
        Returns:
            bool: True if display should be on
        """
        if not self.user_power_state:
            return False
            
        if self.bedtime_manager.is_bedtime():
            return False
            
        return True
    
    def update_display(self, colors: List[Tuple[int, int, int]], color_key: List[Tuple[int, int, int]]) -> None:
        """Update the LED display with new colors.
        
        Args:
            colors: List of RGB tuples for train display LEDs
            color_key: List of RGB tuples for color key LEDs
        """
        # Store the colors for power-on restore
        self._last_colors = colors[:self.led_count]
        self._last_color_key = color_key[:self.color_key_count]

        if not self.is_display_on():
            self.clear_display()
            # Record LED update for health monitoring even when display is off
            if self.metrics:
                self.metrics.record_led_update()
            return
        
        # If network is disconnected, show network status instead
        if self._network_status != 'connected':
            self._show_network_status()
            return
        
        # Update train display LEDs
        for i, color in enumerate(colors):
            if i < self.led_count:
                self.pixels[i] = color
        
        # Update color key LEDs
        for i, color in enumerate(color_key):
            if i < self.color_key_count:
                self.pixels[-(i+1)] = color
        
        self.pixels.show()
        
        # Record LED update for health monitoring
        if self.metrics:
            self.metrics.record_led_update()
    
    def _show_network_status(self) -> None:
        """Display network status using LEDs."""
        if self._network_status == 'disconnected':
            color = NETWORK_DISCONNECTED_COLOR
        else:  # reconnecting
            color = NETWORK_RECONNECTING_COLOR
        
        # Fill all LEDs with the status color
        self.pixels.fill(color)
        self.pixels.show()
        
        # Record LED update for health monitoring
        if self.metrics:
            self.metrics.record_led_update()
    
    def set_network_status(self, status: str) -> None:
        """Update network status and display.
        
        Args:
            status: Network status ('connected', 'disconnected', or 'reconnecting')
        """
        if status not in ['connected', 'disconnected', 'reconnecting']:
            raise ValueError(f"Invalid network status: {status}")
        
        self._network_status = status
        
        if self.is_display_on():
            if status == 'connected':
                # Restore normal display
                self.update_display(self._last_colors, self._last_color_key)
            else:
                # Show network status
                self._show_network_status()
    
    def _hardware_brightness(self, user_brightness: float) -> float:
        """Map user/settings brightness (0–1) to NeoPixel hardware brightness."""
        scaled = user_brightness * BRIGHTNESS_MULTIPLIER
        return max(BRIGHTNESS_MIN, min(BRIGHTNESS_MAX, scaled))
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

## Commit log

2026-01-29 launch code! v1.0 :)
    [bom.csv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]
2026-01-30 added wiring image (fritzing)
2026-02-01 corrected gerber files- still need to correct KiCAD
    [production_red_line-B_Cu.gbr, production_red_line-B_Mask.gbr, production_red_line-B_Paste.gbr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]
2026-02-01 kicad files are/were correct
    [production_red_line_new_silk.kicad_sch]
2026-02-01 updating POS for new kicad/gerber
    [pos.csv]
2026-02-01 cleaning up kicad stuff
2026-05-06 adding headless wifi helper, blue/orange production files, and reorg
    1) Added headless_wifi_helper, making it easier to send pre-flashed boards or move them between locations
    2) Converted all logic to use nmcli as this is the more modern approach
    3) Added orange and blue line production files (they've been ordered! Have yet to receive and test them)
    4) Did some reorganization of production files, gitignore etc
    [Blue Line.kicad_pcb, Blue Line.kicad_sch, Orange Line.kicad_sch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]
2026-06-09 updating station_led_maps and blue line production files
    Turns out ground planes are important ;) I definitely didn't forget to add one in the blue line PCB
    [Blue Line.kicad_pcb]
2026-06-09 Add charlieboard CLI, brightness multiplier, and corrected LED maps. Port terminal settings tooling from private development and fix Blue/Orange station LED direction mappings.
    [constants.py, led_controller.py, settings.py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]
2026-07-09 Revise PCB status for transit lines in README
    Updated the description of the LED display system to reflect the current status of the PCBs for the transit lines.
2026-08-04 implementing speed estimation using lat/lon
    Estimate using lat lon to calculate haversine distance divided by time. Speed is put through exponential moving average to smooth GPS noise and capped at max speed for each line.
    [constants.py, speed_from_position_test.py, test_speed_estimator.py]
2026-08-04 updating for time calculation issue
    [test_speed_estimator.py]

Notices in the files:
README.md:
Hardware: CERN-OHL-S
